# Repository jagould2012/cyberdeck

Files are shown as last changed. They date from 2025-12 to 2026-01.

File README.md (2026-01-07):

# cyberdeck
A custom build of Kali Linux Raspberry Pi’s, fun little radios, all packaged in a portable Pelican case.

### Documentation

Documentation site can be found at [https://jagould2012.github.io/cyberdeck](https://jagould2012.github.io/cyberdeck)

### Bill of Materials

A complete bill of materials can be found [here](https://github.com/jagould2012/cyberdeck/blob/main/bom.csv).

### Custom Plate

The custom plate was manufactured by DataPro using their online [designer](https://www.datapro.net/cgi-bin/plate-designer-pro). All hole and part coordinates can be found [here](https://github.com/jagould2012/cyberdeck/blob/main/plate_drill.csv).

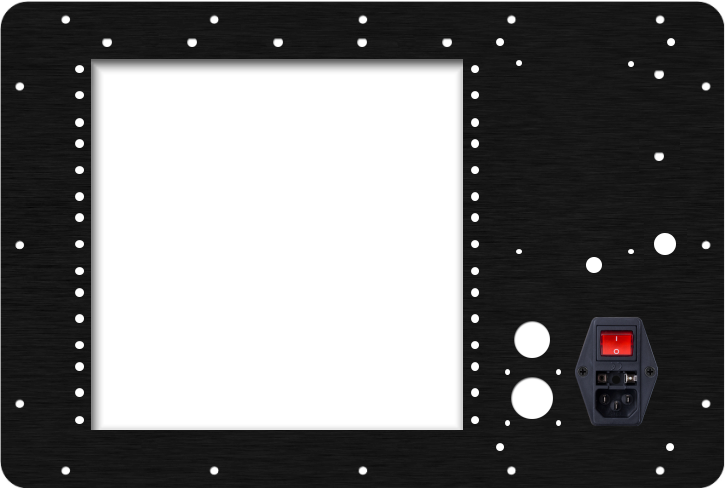
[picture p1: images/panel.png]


Dxf file is available [here](https://github.com/jagould2012/cyberdeck/blob/main/dxf/Panel.dxf).

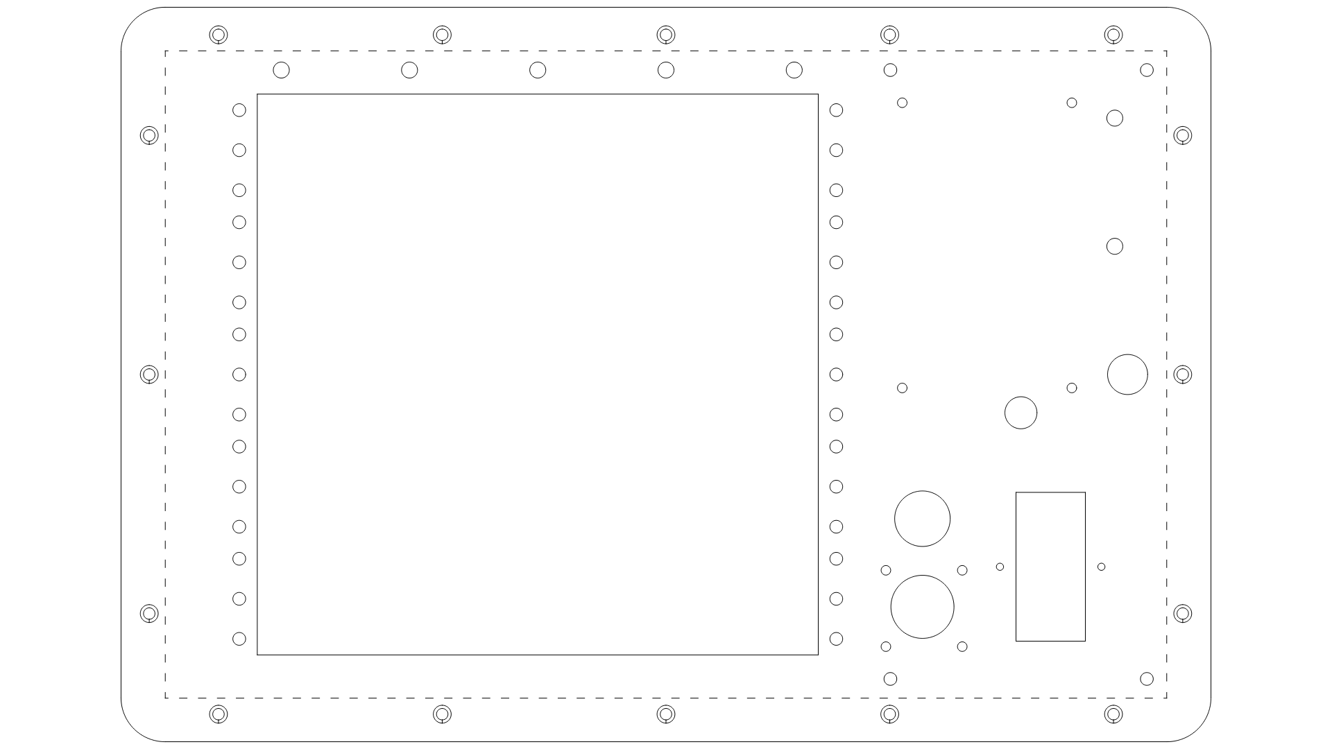
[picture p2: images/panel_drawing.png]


### Power

Wiring diagram for the power supplies, switches, and relays can be downloaded [here](https://github.com/jagould2012/cyberdeck/blob/main/images/power.png).

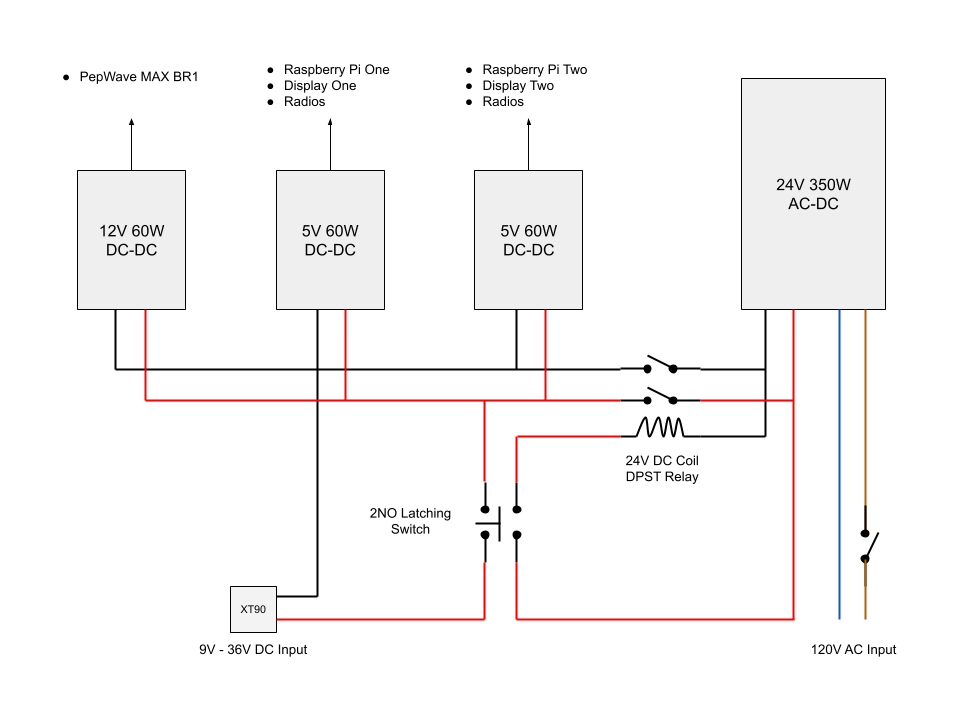
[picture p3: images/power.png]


### Internal Panels

Power supplies and USB devices are mounted to 1/8" ABS panels. Dxf files for the panels can be found [here](https://github.com/jagould2012/cyberdeck/blob/main/dxf/).

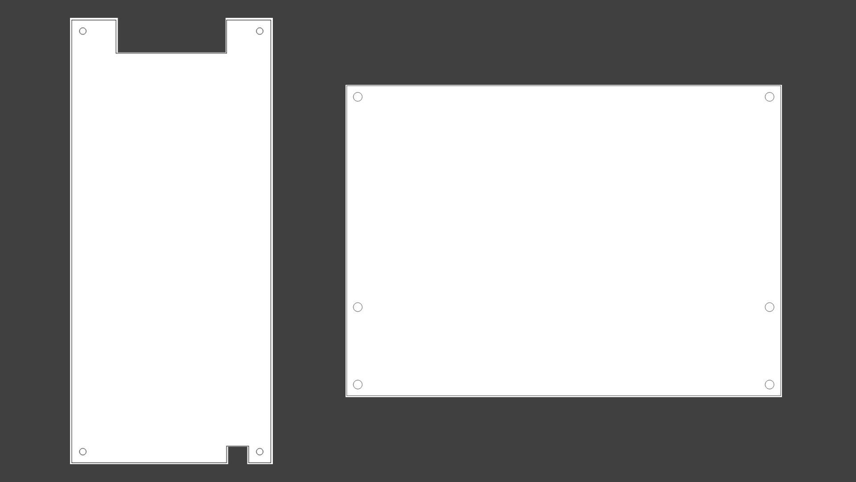
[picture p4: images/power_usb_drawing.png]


### Assembly

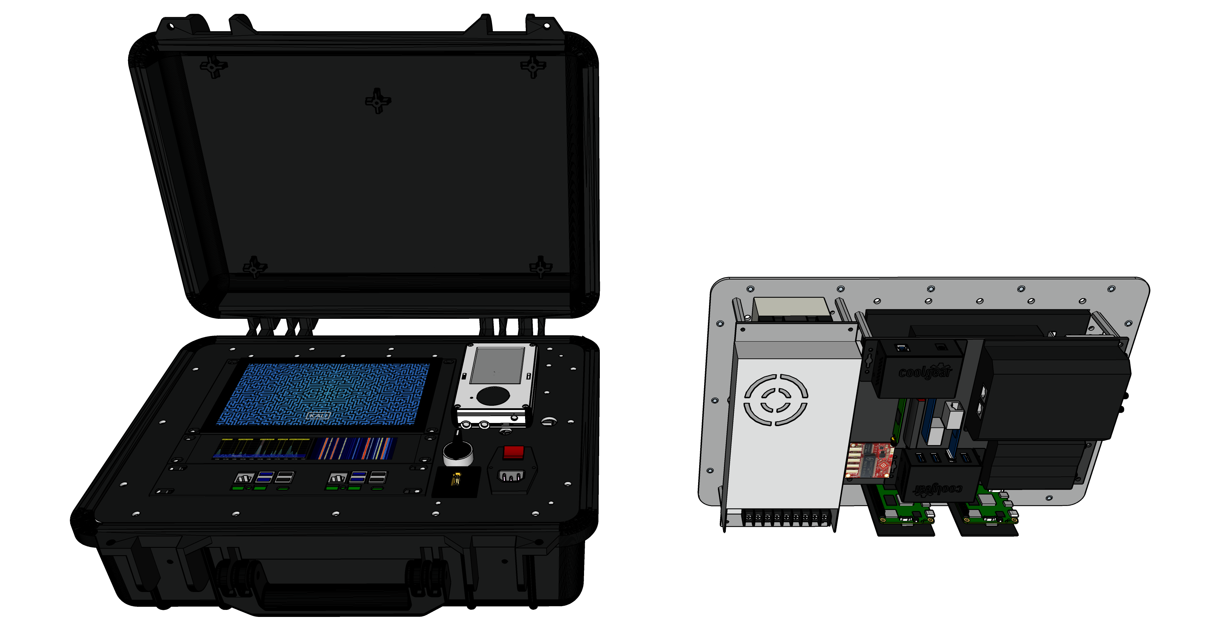
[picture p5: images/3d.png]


Sketchup model is available [here](./Cyberdeck.skp) to assist in assembly.

### Stand

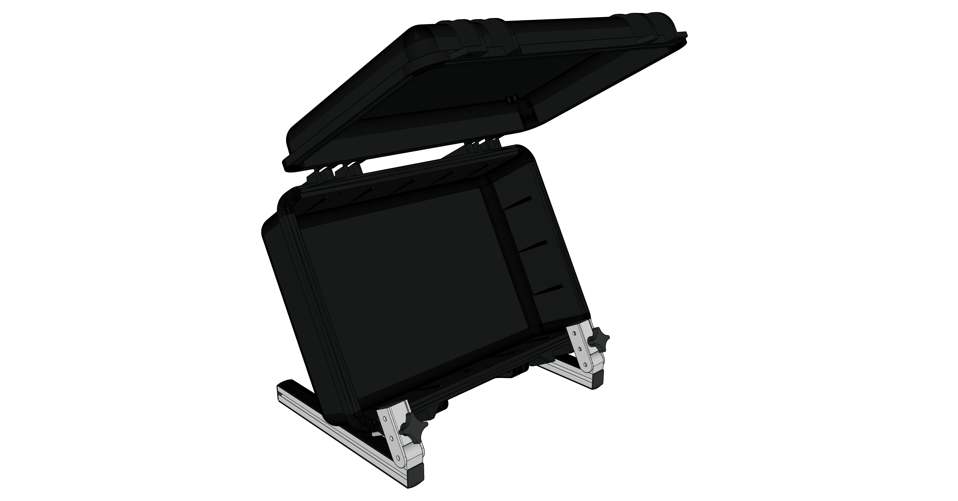
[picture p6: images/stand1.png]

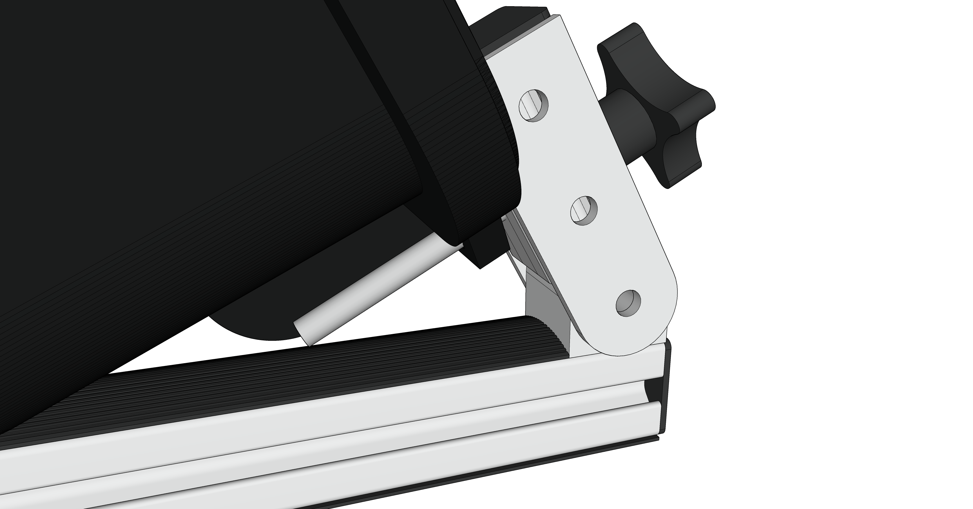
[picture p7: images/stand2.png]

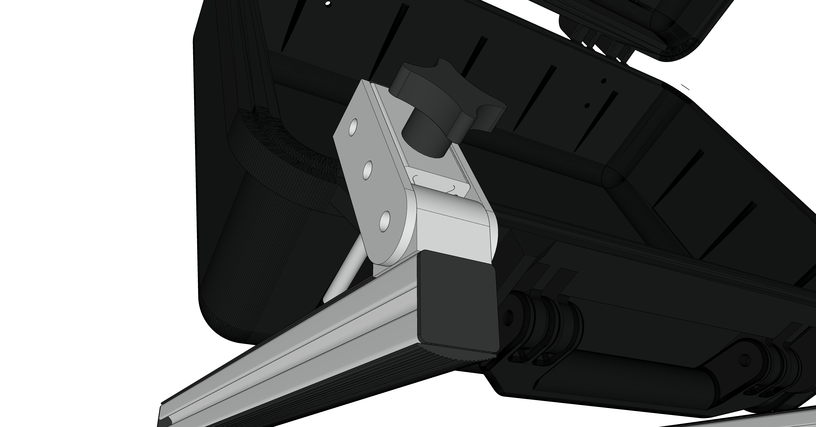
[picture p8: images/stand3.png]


An option stand design is constucted from aluminum t-slot rail.

Sketchup model of the stand is available [here](./Stand) to assist in assembly.

The stand bill of materials is available [here](stand.bom.csv).

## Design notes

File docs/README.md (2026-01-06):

# Cyberdeck
A custom build of Kali Linux Raspberry Pi’s, fun little radios, all packaged in a portable Pelican case.

### Why

Very good question. Why not? 🤷‍♂️

While many people would have varying uses for a project like this, here's a few I can personally offer:

* I had accumulated over the years a lot of interesting little boards (SDR, Ubertooth One, etc) and wanted to have them all put together in one place and be more usable.

* It was a great distraction over the 2025 holidays and gave me a much needed mental break from work.

* I'll occasionally get some professional use out of it when working on IoT projects, being able to inspect raw radio packets, etc.

* It's a lot of fun on the weekends to sit and listen to various radio traffic out there - Fire, EMS, Police, Air Traffic, etc.

* In a natural disaster, civil unrest, etc where we could possibly lose cellular and internet access - it could become quite useful to get comms up with the outside world.

* Lets face it, between the radios in the project and capabilities of Kali Linux, this is a giant rabbit hole of learning. I love to learn new things, and this will bring years of enjoyment.

### Parts

* A complete bill of materials can be found [here](https://github.com/jagould2012/cyberdeck/blob/main/bom.csv) for the project.
* The optional stand bill of materials is [here](https://github.com/jagould2012/cyberdeck/blob/main/stand.bom.csv).

### Cost

While many enthusiasts have a lot of these parts laying around from previous projects (Raspberry Pi, power supplies, assorted cables), if you were to start from scratch and order each item, the cost of the materials is about $3400. The optional stand is about $150 to build. 
<br><sub>(Prices as of Jan 6, 2026)</sub>

### Technical Materials

* All software, drawings, 3D models (Sketchup) can be found in the Github [repository](https://github.com/jagould2012/cyberdeck).

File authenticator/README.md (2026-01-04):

# Cyberdeck Login

A BLE-based remote authentication system for Raspberry Pi computers. Authenticate to your devices from your iPhone without typing passwords.

## Overview

Cyberdeck Login allows you to unlock your Raspberry Pi (or other Linux) computers remotely via Bluetooth Low Energy (BLE). The system uses public key cryptography to ensure secure, passwordless authentication.

### How It Works

1. **Server** advertises via BLE when the device is locked/away, broadcasting:
   - Computer name
   - Random nonce (changes frequently)
   - Timestamp

2. **iPhone App** detects the advertisement, signs the nonce with its private key, and sends back the signed response via BLE

3. **Server** verifies the signature against registered public keys and triggers PAM login for the configured user

### Security Features

- **Public Key Cryptography**: Ed25519 signatures for authentication
- **Nonce-based**: Fresh nonce for each authentication attempt
- **Replay Attack Prevention**: Nonces are invalidated immediately after use and rotate frequently
- **No Password Transmission**: Only cryptographic signatures are exchanged

## Project Structure

```
cyberdeck-login/
├── README.md           # This file
├── server/             # Node.js BLE server
│   ├── Dockerfile
│   ├── docker-compose.yml
│   ├── package.json
│   └── src/
├── config/             # PAM configuration and scripts
│   └── README.md
└── app/                # iOS Swift app example code
    └── README.md
```

## Quick Start

### 1. Set Up the Server

```bash
cd server
docker-compose up -d
```

### 2. Configure PAM

Follow the instructions in `config/README.md` to install the PAM module.

### 3. Register Your iPhone

1. Put the server in registration mode:
   ```bash
   docker exec cyberdeck-login-server node register-mode.js
   ```

2. In the iOS app, go to Settings → Register Device

3. The server will capture your public key in the `publicKeys/` directory

4. Manually move the key to `config.json`:
   ```bash
   # Review the captured key
   cat data/publicKeys/<device-id>.json
   
   # Add it to config.json registered devices
   ```

### 4. Test Authentication

Lock your Raspberry Pi and use the iOS app to authenticate!

## Configuration

### Server Configuration (`data/config.json`)

```json
{
  "computerName": "my-raspberry-pi",
  "loginUser": "pi",
  "nonceRotationIntervalMs": 30000,
  "registeredDevices": [
    {
      "name": "My iPhone",
      "publicKey": "base64-encoded-ed25519-public-key"
    }
  ]
}
```

### Volume Mounts

The server expects a `data/` volume containing:
- `config.json` - Main configuration
- `publicKeys/` - Directory for captured public keys during registration

## Requirements

### Server (Raspberry Pi)
- Docker and Docker Compose
- Bluetooth 4.0+ adapter
- Linux with PAM support

### iOS App
- iOS 14.0+
- iPhone with Bluetooth

## Security Considerations

1. **Physical Security**: The server must be physically secured as it can bypass password authentication

2. **Key Management**: Protect your private keys on both server and mobile device

3. **Registration Mode**: Only enable registration mode when actively pairing a new device

4. **Network**: BLE has limited range (~10m), providing implicit proximity verification

## License

MIT License - See LICENSE file for details

## Contributing

Contributions welcome! Please read CONTRIBUTING.md before submitting PRs.

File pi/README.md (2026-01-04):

# Cyberdeck Raspberry Pi Setup

Automated setup for Raspberry Pi devices running Kali Linux with SDR software stack, Docker, and Synchronet BBS.

## Quick Start

### 1. Flash Kali Linux

1. Download a Kali Linux ARM64 image
2. Flash to SD card with Raspberry Pi Imager
3. Boot the Raspberry Pi
4. (Optional) Install to NVMe:
   ```bash
   wget http://archive.raspberrypi.org/debian/pool/main/r/rpi-imager/rpi-imager_2.0.1_arm64.deb
   sudo dpkg -i rpi-imager_2.0.1_arm64.deb
   sudo rpi-imager &
   ```
5. Use rpi-imager to install Kali Linux to the NVMe drive
6. Remove the SD card and reboot

Recommended at this point to install available updates:

```
sudo apt-get update && sudo apt upgrade -y && sudo apt dist-upgrade -y && sudo reboot
```

### 2. Initial Network Setup

Before running Ansible, ensure the Pi is accessible:

```bash
# Install your SSH key (from Mac/controller)
ssh-copy-id kali@<pi-ip-address>
```

### 3. Run Ansible Playbooks

From the `ansible/` directory on your controller machine:

```bash
# Install dependencies
ansible-galaxy collection install -r requirements.yml

# Run full setup on all hosts
ansible-playbook site.yml -K

# Or target specific hosts (include localhost for BBS deployment)
ansible-playbook site.yml -K --limit "localhost,cyberdeck-pi1"

# Or run individual playbooks
ansible-playbook playbooks/docker-install.yml -K --limit cyberdeck-pi1
```

## What Gets Installed

The Ansible playbooks configure:

- **System Configuration**
  - Boot config (HDMI hotplug, fan control, USB power)
  - Custom hostname
  - WiFi MAC override (for duplicate MAC issues)
  - SSH host key regeneration
  - Sleep/suspend disabled

- **Networking**
  - NetworkManager as primary network manager
  - mDNS/Avahi for `.local` hostname resolution
  - Conflicting services disabled (netplan, systemd-networkd)

- **Docker**
  - Docker CE with compose plugin
  - QEMU user-mode emulation for cross-architecture containers
  - Portainer web UI

- **SDR Software**
  - SDR++ (sdrpp)
  - Universal Radio Hacker (urh)
  - SDRAngel (sdrangel)
  - Base SDR dependencies and udev rules

- **Synchronet BBS**
  - Pre-built Docker container
  - ARM64 native build with SpiderMonkey fix

## Directory Structure

```
pi/
├── ansible/           # Ansible playbooks and configuration
│   ├── inventory.yml  # Host definitions
│   ├── site.yml       # Main orchestration playbook
│   └── playbooks/     # Individual playbooks
├── bbs/               # Synchronet BBS Docker setup
├── sdrangel/          # SDRAngel Docker builder
└── kernel/            # Custom kernel build (optional)
```

## Inventory

Edit `ansible/inventory.yml` to configure your hosts:

```yaml
raspberry_pis:
  children:
    pi:
      hosts:
        cyberdeck-pi1:
          ansible_host: 10.0.0.100
          custom_hostname: cyberdeck-pi1
        cyberdeck-pi2:
          ansible_host: 10.0.0.101
          custom_hostname: cyberdeck-pi2
          wifi_mac_override: "AA:BB:CC:DD:EE:FF"  # Optional
```

## Custom Kernel (Optional)

The default Kali kernel for Raspberry Pi uses 16KB page sizes. Some software requires 4KB pages (e.g., certain Node.js modules like Sharp).

Check your current page size:
```bash
getconf PAGESIZE
```

If you need 4KB pages, see the `kernel/` directory for a Dockerfile that builds a custom kernel. Note: This affects system performance and should only be used when necessary.

## Troubleshooting

### Network Issues

If mDNS isn't working:

```bash
# Check avahi is running
sudo systemctl status avahi-daemon

# Check NetworkManager is managing interfaces
nmcli device status
```

## Manual Commands Reference

While Ansible handles everything, here are useful manual commands:

```bash
# Reboot a host
ansible-playbook playbooks/reboot.yml -K --limit cyberdeck-pi1

# Check BBS status
ssh cyberdeck-pi1.local "docker logs -f SynchronetBBS"

# Connect to BBS
ssh -p 10022 cyberdeck-pi1.local
```

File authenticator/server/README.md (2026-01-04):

# Cyberdeck Login Server

Node.js BLE server that handles authentication requests from the iOS app.

## Prerequisites

- Docker and Docker Compose (for production)
- Node.js 18+ (for development)
- Bluetooth 4.0+ adapter (or use proxy mode for VMs)
- Linux system with D-Bus (for lock screen monitoring)

## Quick Start

1. **Configure environment**

   ```bash
   cp .env.example .env
   nano .env
   ```

2. **Install dependencies**

   ```bash
   npm install
   ```

3. **Start the server**

   ```bash
   npm run dev
   ```

## Configuration

### Environment Variables (`.env`)

```bash
# Path to config.json
CONFIG_PATH=./data/config.json

# Directory for captured public keys during registration
PUBLIC_KEYS_DIR=./data/publicKeys

# Computer name shown in BLE advertisement
COMPUTER_NAME=cyberdeck

# Linux user to log in
LOGIN_USER=pi

# BLE Mode: 'native' for real Bluetooth, 'tcp' for proxy mode
BLE_MODE=native

# TCP port for proxy mode (only used when BLE_MODE=tcp)
TCP_PORT=3100
```

### Server Settings (`data/config.json`)

```json
{
  "computerName": "my-raspberry-pi",
  "loginUser": "pi",
  "nonceRotationIntervalMs": 30000
}
```

## Directory Structure

```
data/
├── config.json      # Server settings
├── publicKeys/      # Captured keys from registration attempts
│   └── <device-id>.json
└── registered/      # Approved devices (copy files here to enable)
    └── <device-id>.json
```

## Device Registration

Registration is always enabled. When an iPhone registers, its public key is saved to `publicKeys/`. To approve a device, copy its file to `registered/`.

1. **Register from iPhone app** (Settings → Register Device)
   
   Server logs:
   ```
   📝 Registration request from: Jonathan's iPhone
   📝 Captured public key saved to ./data/publicKeys/ABC123.json
      To register: cp ./data/publicKeys/ABC123.json ./data/registered/
   ```

2. **Review the captured key**

   ```bash
   cat data/publicKeys/ABC123.json
   ```

3. **Approve the device**

   ```bash
   cp data/publicKeys/ABC123.json data/registered/
   ```

   Server auto-detects and logs:
   ```
   🔑 1 registered device(s) in ./data/registered
      ✨ New device(s) added!
   ```

4. **Revoke a device**

   ```bash
   rm data/registered/ABC123.json
   ```

   Server logs:
   ```
   🔑 0 registered device(s) in ./data/registered
      🗑️  Device(s) removed
   ```

## Proxy Mode (for VMs)

If running in a VM without Bluetooth access, use proxy mode. A Mac with Bluetooth acts as a BLE bridge.

### Architecture

```
iPhone ←→ BLE ←→ Mac (proxy) ←→ WebSocket ←→ VM (server)
```

### Setup

**On the VM:**

```bash
# Set proxy mode in .env
echo "BLE_MODE=tcp" >> .env
echo "TCP_PORT=3100" >> .env

# Start server
npm run dev
```

Output:
```
📡 BLE Mode: tcp
📡 WebSocket server listening on port 3100
✅ Cyberdeck Login Server running (proxy mode)
   Waiting for proxy connection on port 3100...
```

**On the Mac:**

```bash
cd tools/ble-proxy
npm install
npm start -- --server <VM_IP>:3100
```

Output:
```
🔗 BLE Proxy - connecting to ws://<VM_IP>:3100
✅ Connected to server
🔗 Server ready
📡 Bluetooth: poweredOn
✅ BLE advertising - iPhone can now connect
```

Now the iPhone app will see "CyberdeckProxy" and can authenticate through the VM.

## BLE Service Details

### Service UUID: `CD10`

### Characteristics

| UUID | Name | Properties | Description |
|---|---|---|---|
| `CD11` | Challenge | Read | Returns current challenge (nonce, timestamp, computerName) |
| `CD12` | Auth | Write | Accepts signed authentication response |
| `CD13` | Register | Write | Accepts public key registration |

### Challenge Format (JSON)

```json
{
  "nonce": "base64-encoded-32-byte-random",
  "timestamp": 1699999999999,
  "computerName": "my-raspberry-pi"
}
```

### Auth Request Format (JSON)

```json
{
  "signedNonce": "base64-encoded-ed25519-signature",
  "publicKey": "base64-encoded-public-key"
}
```

## Docker Deployment

```bash
docker-compose up -d
```

The container needs:
- Privileged mode (for Bluetooth)
- Host network (for BLE)
- Volume mounts for `/data` and D-Bus

## Troubleshooting

### Bluetooth not working

```bash
# Check Bluetooth status
bluetoothctl show

# Restart Bluetooth service
sudo systemctl restart bluetooth

# Verify adapter is visible
hciconfig
```

### D-Bus errors

```bash
export DBUS_SESSION_BUS_ADDRESS="unix:path=/run/user/$(id -u)/bus"
npm run dev
```

### Lock screen not detected

The server supports:
- systemd-logind (via `loginctl`)
- GNOME Screensaver (via D-Bus)
- KDE Screensaver (via D-Bus)
- freedesktop.org Screensaver standard

### Proxy mode connection issues

```bash
# Check VM is reachable
ping <VM_IP>

# Check port is open
nc -zv <VM_IP> 3100

# Check server is listening
# On VM:
ss -tlnp | grep 3100
```

## Architecture

```
┌─────────────────────────────────────────────────────┐
│                   CyberdeckLoginServer              │
├─────────────────────────────────────────────────────┤
│                                                     │
│  Native Mode:           Proxy Mode:                 │
│  ┌─────────────┐        ┌─────────────┐            │
│  │BleAdvertiser│        │ WsBleServer │            │
│  │BlePeripheral│        │ (WebSocket) │            │
│  └──────┬──────┘        └──────┬──────┘            │
│         │                      │                    │
│  ┌──────┴──────────────────────┴──────┐            │
│  │            AuthService             │            │
│  │       (Ed25519 verification)       │            │
│  └──────────────────┬─────────────────┘            │
│                     │                               │
│  ┌──────────────────┴─────────────────┐            │
│  │           ConfigManager            │            │
│  │    (watches registered/ folder)    │            │
│  └──────────────────┬─────────────────┘            │
│                     │                               │
│  ┌──────────────────┴─────────────────┐            │
│  │             PamAuth                │            │
│  │      (trigger system login)        │            │
│  └────────────────────────────────────┘            │
└─────────────────────────────────────────────────────┘
```

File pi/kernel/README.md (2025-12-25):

# Kali Linux Kernel Builder for Raspberry Pi 5 (4KB Pages)

This Dockerfile creates a build environment for compiling the Kali Linux kernel with
the Raspberry Pi 5 configuration, modified to use **4KB page size** instead of the
default 16KB page size.

## Why 4KB Page Size?

The Raspberry Pi 5 (BCM2712) kernel defaults to 16KB pages for improved performance
in certain workloads. However, some software and use cases require or benefit from
4KB pages:

- Better memory efficiency for applications with small allocations
- Compatibility with software that assumes 4KB pages
- Reduced memory fragmentation in some scenarios
- Required for certain virtualization and container workloads

## Prerequisites

- Docker installed on your Mac M4 (or other ARM64 system)
- At least 20GB of free disk space
- Internet connection for downloading kernel source

## Quick Start

### 1. Build the Docker image

```bash
docker build -t kali-rpi5-kernel .
```

This will:
- Pull the latest Kali Linux rolling release
- Install all kernel build dependencies
- Clone the Raspberry Pi Linux kernel source (rpi-6.6.y branch)
- Apply the bcm2712_defconfig (Raspberry Pi 5)
- Modify the config to use 4KB pages

### 2. Build the kernel

```bash
mkdir -p output
docker run -it --rm -v $(pwd)/output:/output kali-rpi5-kernel /build/build-kernel.sh
```

This will compile the kernel and copy the artifacts to `./output/`:
- `boot/kernel8-4k.img` - The kernel image
- `boot/*.dtb` - Device tree blobs
- `boot/overlays/` - Device tree overlays
- `modules/lib/modules/<version>/` - Kernel modules
- `kernel-config-4k` - The kernel configuration used

### 3. Install on Raspberry Pi 5

1. Copy the kernel and DTBs:
   ```bash
   sudo cp output/boot/kernel8-4k.img /boot/firmware/
   sudo cp output/boot/*.dtb /boot/firmware/
   sudo cp -r output/boot/overlays/* /boot/firmware/overlays/
   ```

2. Install the modules:
   ```bash
   sudo cp -r output/modules/lib/modules/* /lib/modules/
   sudo depmod -a
   ```

3. Configure boot to use the new kernel:
   ```bash
   echo "kernel=kernel8-4k.img" | sudo tee -a /boot/firmware/config.txt
   ```

4. Reboot:
   ```bash
   sudo reboot
   ```

5. Verify after reboot:
   ```bash
   uname -r  # Should show the new kernel version with -v8-4k-kali suffix
   getconf PAGESIZE  # Should return 4096 (4KB)
   ```

## Additional Commands

### View current configuration
```bash
docker run -it --rm kali-rpi5-kernel /build/show-config.sh
```

### Interactive shell
```bash
docker run -it --rm kali-rpi5-kernel bash
```

### Run menuconfig for additional customization
```bash
docker run -it --rm -v $(pwd)/output:/output kali-rpi5-kernel \
    bash -c "cd /build/linux && make menuconfig && /build/build-kernel.sh"
```

### Use a different kernel branch
```bash
docker build --build-arg KERNEL_BRANCH=rpi-6.12.y -t kali-rpi5-kernel .
```

## Configuration Changes

The only modification made to the stock `bcm2712_defconfig` is:

| Setting | Original | Modified |
|---|---|---|
| `CONFIG_ARM64_16K_PAGES` | `y` | not set |
| `CONFIG_ARM64_4K_PAGES` | not set | `y` |
| `CONFIG_LOCALVERSION` | `"-v8-16k"` | `"-v8-4k-kali"` |

## Build Time

On a Mac M4:
- Docker image build: ~5-10 minutes
- Kernel compilation: ~15-30 minutes (depending on CPU cores)

## Troubleshooting

### Build fails with out of memory
Increase Docker's memory allocation in Docker Desktop settings.

### Modules don't load after installation
Run `sudo depmod -a` and ensure the module directory name matches `uname -r`.

### Kernel panic on boot
The 4KB page size kernel may not be compatible with all Raspberry Pi 5 
configurations. You can revert by removing `kernel=kernel8-4k.img` from 
`/boot/firmware/config.txt` (edit the SD card on another computer if needed).

## References

- [Raspberry Pi Linux Kernel](https://github.com/raspberrypi/linux)
- [Kali ARM Build Scripts](https://gitlab.com/kalilinux/build-scripts/kali-arm)
- [Raspberry Pi Kernel Documentation](https://www.raspberrypi.com/documentation/computers/linux_kernel.html)

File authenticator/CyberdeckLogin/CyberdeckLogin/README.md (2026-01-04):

# Cyberdeck Login iOS App

Example Swift code for the Cyberdeck Login iOS app.

## Overview

This directory contains example Swift code demonstrating the core functionality needed for the iOS app. You will need to create an Xcode project and integrate this code.

## Project Setup

1. Create a new iOS project in Xcode
   - Product Name: `Cyberdeck Login`
   - Bundle Identifier: `com.yourcompany.cyberdeck-login`
   - Language: Swift
   - Minimum iOS: 14.0

2. Add required capabilities in Xcode:
   - Background Modes → Uses Bluetooth LE accessories
   - Background Modes → Acts as a Bluetooth LE accessory (for registration)

3. Add to Info.plist:
   ```xml
   <key>NSBluetoothAlwaysUsageDescription</key>
   <string>Cyberdeck Login uses Bluetooth to authenticate with your devices</string>
   <key>NSBluetoothPeripheralUsageDescription</key>
   <string>Cyberdeck Login uses Bluetooth to authenticate with your devices</string>
   ```

4. Copy the Swift files from this directory into your project

## File Structure

```
app/
├── README.md                 # This file
├── CyberdeckLoginApp.swift   # Main app entry point
├── Models/
│   ├── Device.swift          # Device model
│   └── KeyPair.swift         # Cryptographic key pair
├── Services/
│   ├── BLEManager.swift      # Bluetooth LE manager
│   ├── CryptoService.swift   # Ed25519 signing
│   └── KeychainService.swift # Secure key storage
├── Views/
│   ├── ContentView.swift     # Main view
│   ├── DeviceListView.swift  # Nearby devices list
│   ├── DeviceDetailView.swift# Single device view
│   └── SettingsView.swift    # Settings & registration
└── ViewModels/
    └── DeviceViewModel.swift # Device state management
```

## Core Components

### BLE Service UUIDs

```swift
let CYBERDECK_SERVICE_UUID = CBUUID(string: "CD10")
let CHALLENGE_CHAR_UUID = CBUUID(string: "CD11")
let AUTH_CHAR_UUID = CBUUID(string: "CD12")
let REGISTER_CHAR_UUID = CBUUID(string: "CD13")
```

### Authentication Flow

1. **Discover** nearby Cyberdeck devices (scanning for `CD10` service)
2. **Connect** to the device
3. **Read** the challenge from `CD11` characteristic (nonce + timestamp)
4. **Sign** the challenge with device's Ed25519 private key
5. **Write** signed response to `CD12` characteristic
6. **Receive** success/failure result

### Key Management

- Keys are generated using Ed25519 (via CryptoKit on iOS 13+ or TweetNaCl)
- Private key stored securely in iOS Keychain
- Public key can be exported for registration

## Dependencies

The example code uses only Apple frameworks:
- `CoreBluetooth` - BLE communication
- `CryptoKit` - Ed25519 signing (iOS 13+)
- `Security` - Keychain access

## Building

1. Open your Xcode project
2. Copy the Swift files into your project
3. Build and run on a physical device (BLE doesn't work in simulator)

## Usage

### First Time Setup

1. Open the app
2. Go to Settings → Generate Keys (if not already done)
3. Put your Raspberry Pi server in registration mode
4. Tap "Register Device" in the app
5. Wait for registration confirmation

### Authentication

1. Lock your Raspberry Pi
2. Open the app on your iPhone
3. The device should appear in the list
4. Tap to authenticate
5. Your Raspberry Pi should unlock!

## Troubleshooting

### Device not appearing
- Ensure Bluetooth is enabled on both devices
- Check that the server is running and in locked state
- Verify BLE advertising is working

### Authentication failing
- Check that your public key is registered in config.json
- Verify system clocks are synchronized (within 60 seconds)
- Check server logs for detailed error messages

### Keys not generating
- Ensure the app has Keychain access
- Try deleting and regenerating keys in Settings

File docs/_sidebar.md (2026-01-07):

<!-- GENERATED FILE - DO NOT EDIT -->
* [Home](/)
* Instructions
  * [Pelican Case](/instructions/case.md)
  * [Power Board](/instructions/power.md)
  * [USB Board](/instructions/usb.md)
  * [Front Plate](/instructions/front.md)
  * [Assembly and Power Up](/instructions/assembly.md)
  * [Software](/instructions/software.md)
* [Gallery](/gallery.md)

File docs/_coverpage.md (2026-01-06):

<!-- _coverpage.md -->



# Cyberdeck <small>1.0</small>

> A case full of interesting tools.

[GitHub](https://github.com/jagould2012/cyberdeck)
[Get Started](#cyberdeck)

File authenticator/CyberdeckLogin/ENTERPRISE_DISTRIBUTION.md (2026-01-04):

# Enterprise Distribution Guide

This guide covers distributing the Cyberdeck Login app without using the App Store.

## Distribution Options

### Option 1: Apple Developer Enterprise Program (Recommended for organizations)
- Requires Apple Developer Enterprise Program membership ($299/year)
- Can distribute to unlimited devices within your organization
- No App Store review required

### Option 2: Ad Hoc Distribution (Up to 100 devices)
- Requires standard Apple Developer Program ($99/year)
- Limited to 100 registered devices per year
- Good for small teams or personal use

### Option 3: TestFlight (Up to 10,000 testers)
- Requires standard Apple Developer Program
- App review required (but lighter than App Store)
- Good for beta testing

## Ad Hoc Distribution Setup

### 1. Register Devices

Collect UDIDs from all target devices:

```bash
# On Mac with device connected:
system_profiler SPUSBDataType | grep -A 11 "iPhone\|iPad"

# Or use Apple Configurator 2
# Or: Settings → General → About → tap Serial Number until UDID appears
```

Register devices in Apple Developer Portal:
1. Go to https://developer.apple.com/account/resources/devices/list
2. Click (+) to add device
3. Enter device name and UDID

### 2. Create Distribution Certificate

1. On your Mac, open Keychain Access
2. Keychain Access → Certificate Assistant → Request a Certificate from a Certificate Authority
3. Enter email, select "Saved to disk"
4. Go to Apple Developer Portal → Certificates
5. Create new certificate: **Apple Distribution**
6. Upload the CSR file
7. Download and double-click to install

### 3. Create Provisioning Profile

1. Go to Apple Developer Portal → Profiles
2. Click (+) to create new profile
3. Select **Ad Hoc** distribution
4. Select your App ID (or create one: `com.yourcompany.CyberdeckLogin`)
5. Select your Distribution Certificate
6. Select all devices that should be able to install
7. Name it: `CyberdeckLogin AdHoc`
8. Download the `.mobileprovision` file

### 4. Configure Xcode Project

1. Open project in Xcode
2. Select the project → Signing & Capabilities
3. Uncheck "Automatically manage signing"
4. For **Release** configuration:
   - Import the provisioning profile (drag to Xcode or double-click)
   - Select the profile in "Provisioning Profile" dropdown
   - Select the distribution certificate

### 5. Archive and Export

1. Select **Any iOS Device** as build target
2. Product → Archive
3. When archive completes, click **Distribute App**
4. Select **Release Testing** (adhoc)
5. Choose options:
   - App Thinning: None (or All compatible device variants)
   - Include manifest for over-the-air installation: ✓ (optional)
6. Select your distribution certificate
7. Click **Export**

### 6. Distribution Methods

#### A. Direct Installation via Xcode
1. Connect device to Mac
2. Window → Devices and Simulators
3. Drag .ipa file onto device

#### B. Apple Configurator 2
1. Open Apple Configurator 2
2. Connect device
3. Add → Apps → Choose the .ipa file

#### C. Over-the-Air (OTA) Installation
Requires a web server with HTTPS.

1. During export, check "Include manifest for over-the-air installation"
2. Enter the URLs where files will be hosted:
   - IPA URL: `https://yourserver.com/apps/CyberdeckLogin.ipa`
   - Display Image URL: `https://yourserver.com/apps/icon-57.png`
   - Full Size Image URL: `https://yourserver.com/apps/icon-512.png`

3. Upload to your server:
   - `CyberdeckLogin.ipa`
   - `manifest.plist`
   - Icon images

4. Create an HTML page with install link:
```html
<!DOCTYPE html>
<html>
<head>
    <title>Install Cyberdeck Login</title>
    <meta name="viewport" content="width=device-width, initial-scale=1">
</head>
<body>
    <h1>Cyberdeck Login</h1>
    <a href="itms-services://?action=download-manifest&url=https://yourserver.com/apps/manifest.plist">
        Install App
    </a>
</body>
</html>
```

5. Users visit the page on their iOS device and tap to install

**Note:** The server must use HTTPS with a valid certificate.

#### D. MDM (Mobile Device Management)
For larger organizations, use an MDM solution like:
- Jamf
- Microsoft Intune
- Kandji
- Mosyle

## Watch App Distribution

The Watch app is bundled with the iPhone app automatically:

1. Ensure Watch target is included in the archive
2. The .ipa will contain both iPhone and Watch apps
3. When user installs iPhone app, Watch app is available in Watch app on iPhone

## Updating the App

For Ad Hoc distribution, you need to:
1. Increment the version/build number in Xcode
2. Create a new archive
3. Export with the same provisioning profile
4. Distribute the new .ipa

Users will need to install the new version manually (OTA link or direct install).

## Troubleshooting

### "Unable to Install" Error
- Device UDID not in provisioning profile
- Provisioning profile expired
- App was built for different architecture

### Profile Expired
- Provisioning profiles expire after 1 year
- Create new profile and re-export

### Device Limit Reached
- Ad Hoc is limited to 100 devices per year
- Devices cannot be removed until membership renewal
- Consider Enterprise program for more devices

## Automation with fastlane

For automated builds, use fastlane:

```ruby
# Fastfile
default_platform(:ios)

platform :ios do
  desc "Build and export Ad Hoc IPA"
  lane :adhoc do
    # Increment build number
    increment_build_number
    
    # Build
    build_app(
      scheme: "CyberdeckLogin",
      export_method: "ad-hoc",
      output_directory: "./build",
      output_name: "CyberdeckLogin.ipa"
    )
    
    # Optional: Upload to distribution server
    # scp("./build/CyberdeckLogin.ipa", "user@server:/var/www/apps/")
  end
end
```

Run with:
```bash
fastlane adhoc
```

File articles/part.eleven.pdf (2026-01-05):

## Part Eleven: The Software

medium.com/@jagould2012/part-eleven-the-software-eb3590c60b6b

(side note, Eleven is dead. I don’t believe.)

Automated Configuration

With the build complete (mostly) (https://medium.com/@jagould2012/cyberdeck-part-ten-2958a534caa5) I moved on to the software design of the system. A few key requirements:

All software should be installed on both computers (redundant compute design). While a board is configured to run a certain set of software on boot, it should be able to take over the role of the other board (run Pi 2 boot script on Pi 1 for example)
It should be easy to keep the software installs in sync across boards.
Software should be easy to test on my laptop without necessarily having the case powered up in front of me.

For this task, I turned to my friend (or arch enemy?) Ansible. (https://docs.ansible.com/) Consisting of Playbooks (https://docs.ansible.com/projects/ansible/latest/playbook_guide/playbooks_intro.html#playbook-syntax) (install scripts) and a host Inventory (https://docs.ansible.com/projects/ansible/latest/inventory_guide/intro_inventory.html) (list of target computers), Ansible is an automation software that remotely configures computers over SSH. It’s primarily used for managing large fleets of servers, but can easily be used to maintain desktop computers also. The big advantage is that the configuration can be checked into a source repository, versioned, and updated just like a software project (referred to as “infrastructure as code”).

Let’s face it, if you’ve used Ansible, its a great tool — once you have it working correctly — but you always do question was the time it took to get it working worth what it buys you? However, times have changed, and my other friend / nemesis Claude knows Ansible quite well, so the upfront investment is a lot less than it used to be.

The Ansible configuration, available here, (https://github.com/jagould2012/cyberdeck/tree/main/pi/ansible) does a couple of things:

Builds a few projects on my local machine (conveniently an ARM64 mac) to save time not building on each remote host. This includes the BBS software (Synchronet) and SDRAngel, both of which do not have pre-build ARM packages available for the Pi. Copies and installs all software to each Raspberry Pi and applies global settings I want on every host (disable sleep, configure Network Manager, etc).
Applies host specific configurations — MAC address configuration, which Docker containers should start, etc.
Configures a 3rd host, cyberdeck-testvm.local, which is a copy of Kali Linux running on my Macbook in a Parallels VM.

The test VM allows me to test new software, and develop the Ansible scripts to deploy it, without having to have the Cyberdeck powered up — and more importantly not mess up the Cyberdecks configuration. Each time I sit down to add more to the stack, I can snapshot the VM and reset it if I’m not satisfied with how things turn out. Once I’m happy with my changes, I do a pull request on Github, then run the Ansible playbooks on the Raspberry Pi boards.

At any time, with a swap of the USB cable on the front panel and running a script, Pi 1 can become Pi 2, Pi 2 can become Pi 1, giving me a true redundant system. You wouldn’t want to grab the Pelican case in an emergency, natural disaster, only to find your comms down because of a $100 Raspberry Pi or $50 power supply?

Authentication

This is where the rabbit hole got very deep…

I was thinking through the other day the issue of how I will log into these computers:

I don’t want to make them insecure and have them log in automatically on boot. With just touch screens available on the system, I really hate the idea of an onscreen keyboard to type in a password.
Making the Cyberdeck useless without pulling out the keyboard breaks the whole design (even though I do have a nice keyboard conveniently in the case).

I looked into several hardware key solutions from Yubico and Thetis that use the Fido2 protocol to securely unlock a device. These were interesting options, especially the very small Thetis Nano: (https://www.amazon.com/dp/B0F3JX7F76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)

You plug in the device to a USB port, and press a button on it to initiate the authentication. Using the right PAM module on Linux, the device unlocks.
Some offer a built-in Bluetooth option that allow you to activate the key without plugging it into USB and send the authentication code. However, this is known to be unreliable at the login screen on Linux (apparently works very well in a browser for using the key to log into websites though).
I could leave the key in the USB port the majority of the time, and just remove it when I want to secure the case, but this means anyone can press the button on the key and access the computer.
The Fido2 specification requires the activation to ultimately be on the hardware key, so no options exist to use a phone app, etc to prevent the key from being used if left plugged in.

Not exactly what I was looking for. The ideal scenario to me is that I could power up the case and then use some other device, like my phone or watch, to securely login the Pi computers.

Fine. I’ll do it myself.
— Thanos

After researching the available options, I had developed a list of requirements, but found no existing solution:

Server software running on the Pi that was capable of logging in a pre-selected user. Wireless interface, no plugging in USB devices
Fast means of authenticating from a secure device I already carry daily
Secure login, not vulnerable to capture or replay attacks (I’m not the only person with a Mayhem board).

The server…

Node.js server running in a Docker container.
Advertises every few seconds on BLE and listens for a response.
Generates a new nonce every 30 seconds and updates it advertisement. Stores a list of public keys that have been received from my client app.
If I move a public key from the publicKeys directory to the registered directory, accepts authentication from that device.
When a packet is received, verifies with the public key that the nonce was signed with the matching private key and unlocks the computer.
Uses Linux dbus interface to communicate with the operating system.
Immediately rotates the nonce so that the packet, if captured by a bad actor, can never be used again.

Combined with the correct custom PAM module, we now had a secure way to remotely unlock Linux.

The app…

iPhone, iPad, and Apple Watch app capable of communicating with the server. Built with Swift.
Generates a new public / private key on install (from the settings menu).
When put in ‘register’ mode, sends the public key to the server over Bluetooth. Scans for nearby servers listening on BLE, allows you to connect, authenticate, and send the unlock command.
Using Apples secure connection between the watch and phone and iCloud Keychain, share the private key with attached watches. The watch can now directly connect to the server and send its own unlock commands.
Watch “complication” can be installed on any watch face for quickly launching the login app.

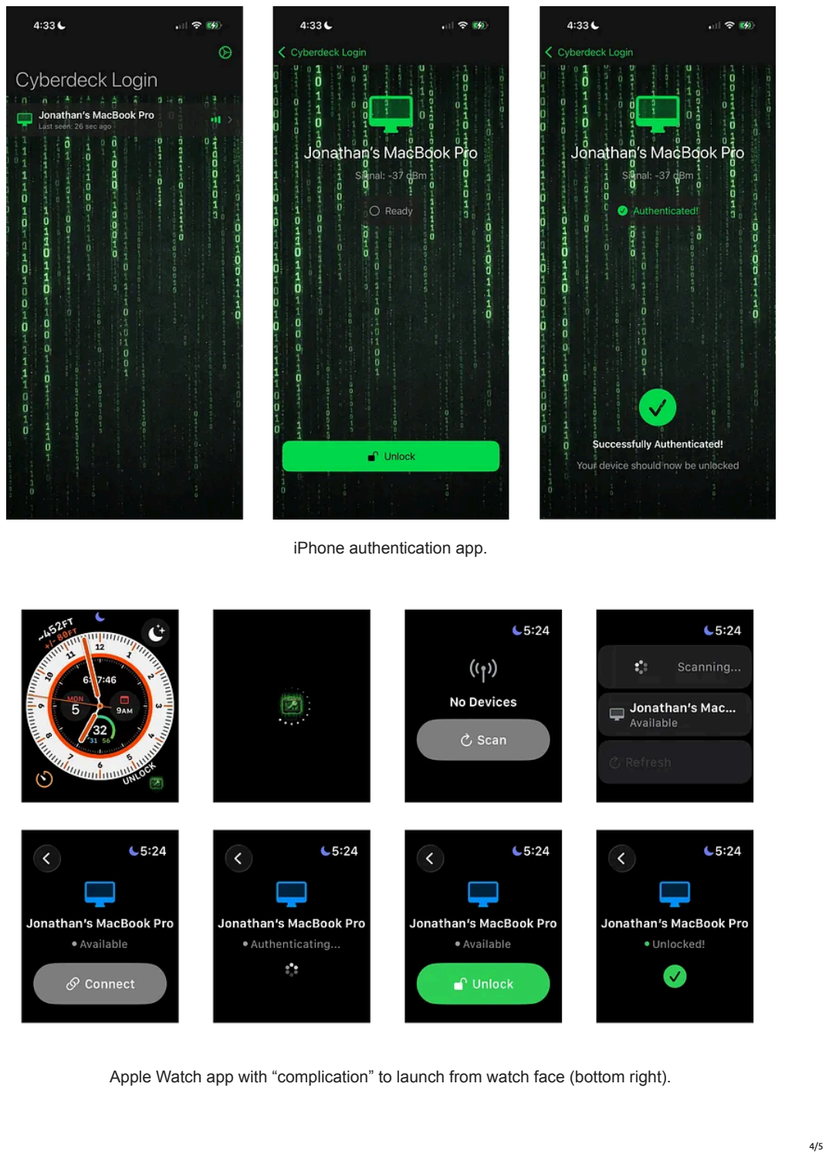
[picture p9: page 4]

iPhone authentication app.

Apple Watch app with “complication” to launch from watch face (bottom right).

Right now I’m distributing it to my personal devices under an enterprise build, but eventually would be willing to put it on the App Store if others are interested. It could become especially interesting as a Cyberdeck companion app with additional features (reboot, power off, WiFi management).

And to be clear — I am completely aware of how overbuilt a solution this is, but it was really fun to get working. And it’s all available on the Github project (https://github.com/jagould2012/cyberdeck/tree/main/authenticator) of course.

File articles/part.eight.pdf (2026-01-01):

## Cyberdeck: Part Eight

medium.com/@jagould2012/cyberdeck-part-eight-22de883a2eab

Back in the 90’s I ran a couple of different bulletin board systems (BBS). I won’t get into all the details of the various “groups” of that time, but one of my favorite BBS software I ever ran was Oblivion/2 (long live Lord Jazz / ACiD / iCE 😉)

Obv/2 is long gone, and despite attempts (https://github.com/M-griffin/Oblivion2-XRM) to resurrect it, no production ready version exist. However, its trademark ANSI art feel has been emulated in a very production ready BBS software called Synchronet. (https://www.synchro.net/)

What in the world does this have to with a Cyberdeck you ask? Well, with the compute power I’ve packed into this Pelican case being thousands of times more than the machines I had in the 90s, I thought it might be fun to have a Docker container at the ready to run a popup BBS from the case any time I want. All reachable through a modern SSH client.

You know, the world is coming to an end, all forms of communication are down… maybe exactly what you need to pass the time is a LoRa connection, a high gain antenna, and a few friends who want to listen to the Seth Able the Bard in the tavern on LORD?

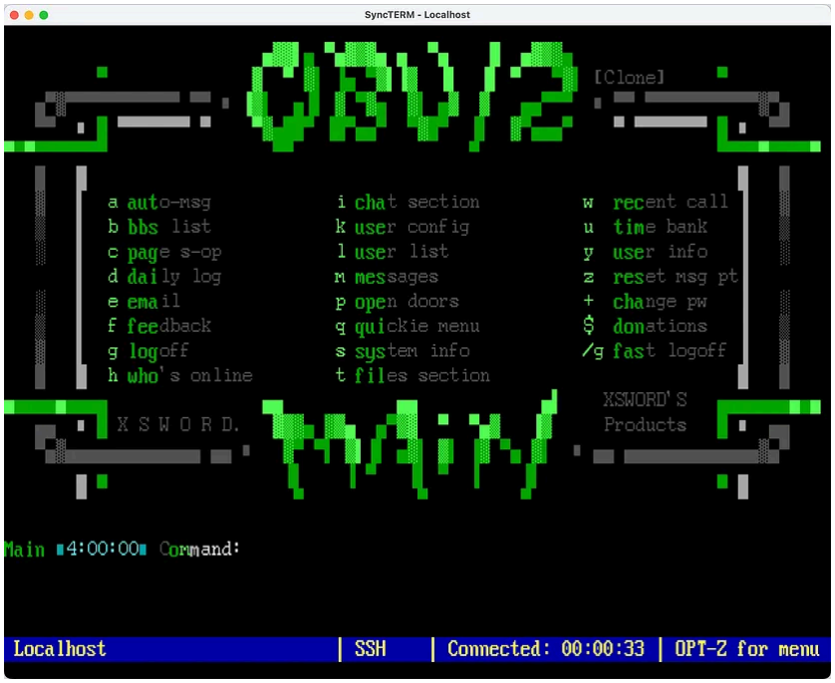
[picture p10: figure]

Synchronet BBS running that all too familiar green menu we all loved.

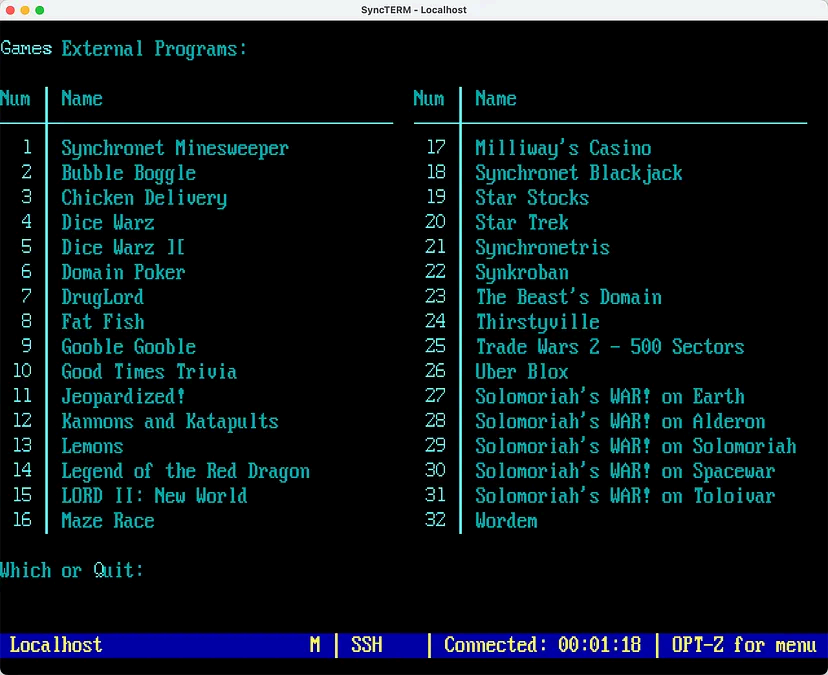
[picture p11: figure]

There’s a list that brings back memories…

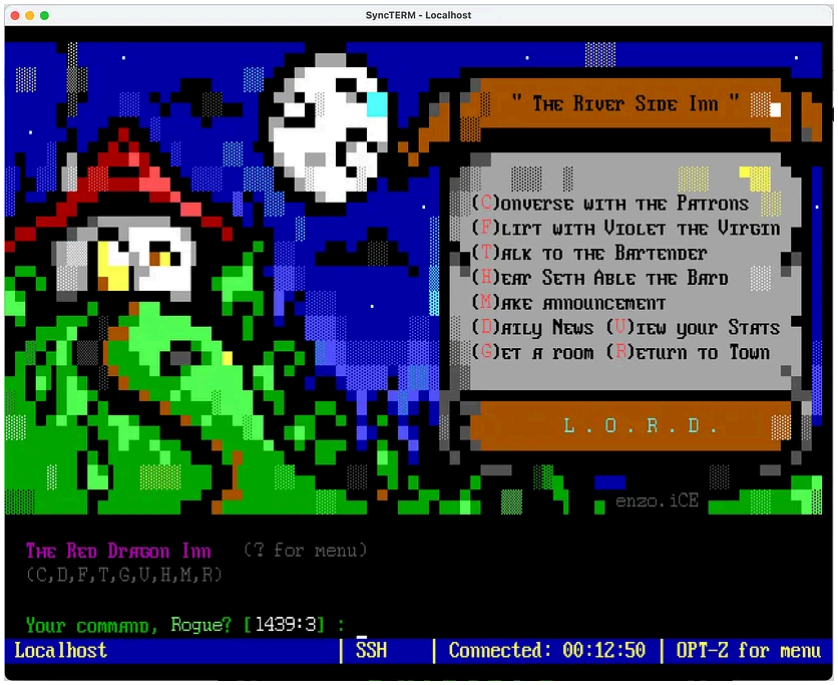
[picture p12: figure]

Let’s just leave poor Violet alone now, ok?

The plan is to use a dynamic DNS service to update my whereabouts whenever the case is powered up so friends can connect. The BBS name? Cyberdeck of course. Hit me up on Fidonet for the new user password. 😳

Currently looking for ANSI artists to commission a custom theme. In the mean time, the Docker configuration is up on GitHub. (https://github.com/jagould2012/cyberdeck)

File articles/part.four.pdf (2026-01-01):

## Cyberdeck: Part Four

medium.com/@jagould2012/cyberdeck-part-three-daf6f7dfc493

As I’ve been waiting for the many Amazon boxes to arrive to start the build, I spent a little time looking through old project boxes to make sure I hadn’t missed anything that would fit nicely in the build. Two new discoveries have been added that I think will be great additions.

PepWave MAX BR1 Mini

With a built-in 4G LTE cellular radio, two Ethernet port switch, and WiFi radio — this will give me a number of options for uplink where available. The WiFi can be configured for Wifi-as-WAN (with an added license), so the device can connect to available Internet and serve it out over the two Ethernet ports to the Raspberry Pi boards. This is particularly helpful as it leaves the AXE3000 WiFi radio I bought available for other purposes (like monitor mode).

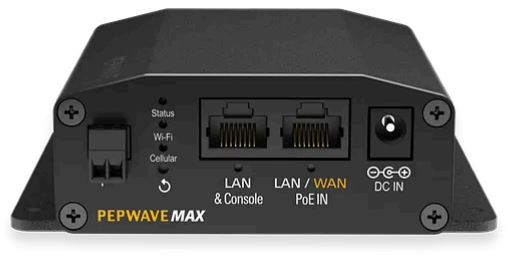
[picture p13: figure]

PepWave MAX BR1 Mini

The device accepts a DC supply of 12–28V DC, which required a slight change in our power design as our main supplies are all 5V (for the LCD displays and Raspberry Pi SBCs). I could have just connected the device to the onboard 24V DC supply, but that would mean the PepWave would only be available when connected to mains.

The power design now includes a third 60W buck boost power supply, this one with a 12V DC output. Using the same family as the 5V supply, it also accepts a wide 9V — 36V DC input (see power supply article). (https://medium.com/@jagould2012/cyberdeck-part-three-b9f26160baa1)

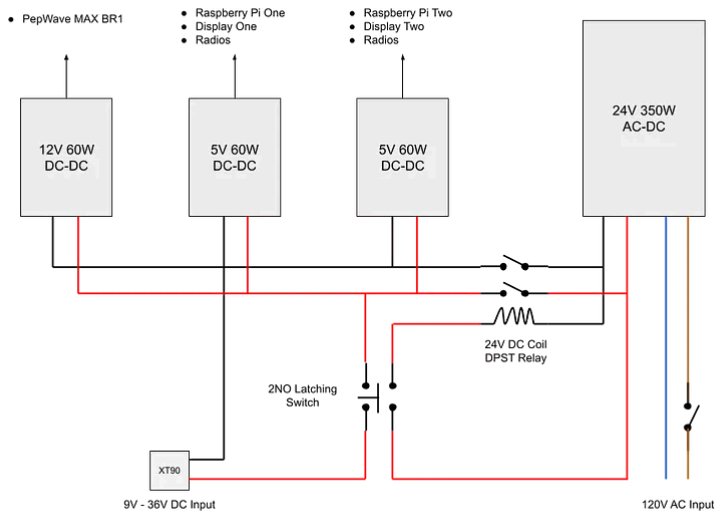
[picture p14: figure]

Addition of a 12V 60W power supply.

60W output is quite a bit more than the PepWave requires, but it will be helpful in the future to have available capacity at both 5V and 12V, all operating on our dual supply design.

Ubertooth One

Another great design from Great Scott Gadgets, the Ubertooth One (https://greatscottgadgets.com/ubertoothone/) provides some great capabilities specifically in the Bluetooth spectrum. It’s an older device thats been retired by the manufacturer, but I remember it being very helpful in the project I originally purchased it for.

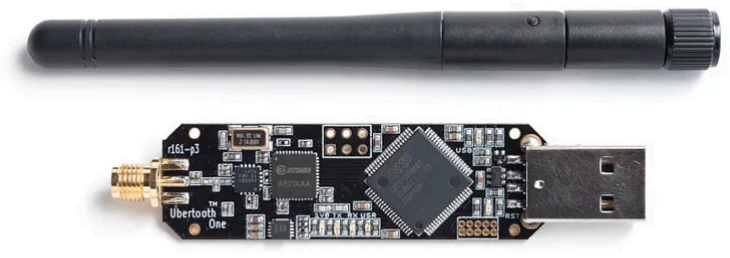
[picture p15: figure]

Great Scott Gadgets Ubertooth One

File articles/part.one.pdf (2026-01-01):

## Cyberdeck: Part One

medium.com/@jagould2012/cyberdeck-part-one-45e778d2b7b9

Over the years I’ve collected all kinds of interesting little radios, from LoRa Meshtastic, to Software Defined Radios (RTL-SDR), and had a few days of fun with each. But over time, most end up on a shelf or in a storage container when I need space on my desk for another project (which is currently a mobile Kubernetes cluster project).

The other day an ad made it into my feed for the Clockwork uConsole (https://www.clockworkpi.com/home-uconsole) that caught my eye. It’s an interesting little handheld device that hosts a Raspberry Pi compute module, a touchscreen, and has an optional board (https://hackergadgets.com/products/uconsole-rtl-sdr-lora-gps-rtc-usb-hub-all-in-one-extension-board) for an SDR. This almost became my next impulse buy gadget, but between the cost of the pieces and the several week lead time, I thought I would do a little more looking around in this “Cyberdeck” world. What else are people building in this space?

Rabbit hole… deep…

Inspired by some pretty cool builds out there, I turned to one of my favorite suppliers of luggage for my diving equipment, Pelican. Beside making complete indestructible cases, they also make some very cool mounting options for projects like this with their Special Application Panel Frames. (https://business.pelican.com/us/en/product/Accessories/1500pf)

With a Pelican 1500 case size in mind, I turned to the good folks at DataPro International who allow you to custom design plates online (https://www.datapro.net/cgi-bin/plate-designer-pro) specifically for the Pelican frames. After a few hours of browsing a variety of LCD screens, mounts, and antennas on Amazon, I started to realize that I didn’t want to invest in a plate with a custom hole in it for a specific size screen, only for it to not be available for replacement or upgrade late, leaving me to buy another custom plate (which can get a bit pricey). I wanted something more configurable that I could change around later and re-use the same plate and case.

Then I remembered another ad I had seen recently for a growing trend in home servers, the 10" format rack. Most of these home servers are single board computer based, and many include small touchscreen LCD displays mounted in the rack.

Perfect.

So, I grabbed my morning coffee, found the specs for the drill pattern, and before long had placed an order for what is basically a 5U 10" format rack in a Pelican case. A few extra holes for SMA bulkheads for antenna, and a power inlet and switch, and we have the beginnings of a pretty great build.

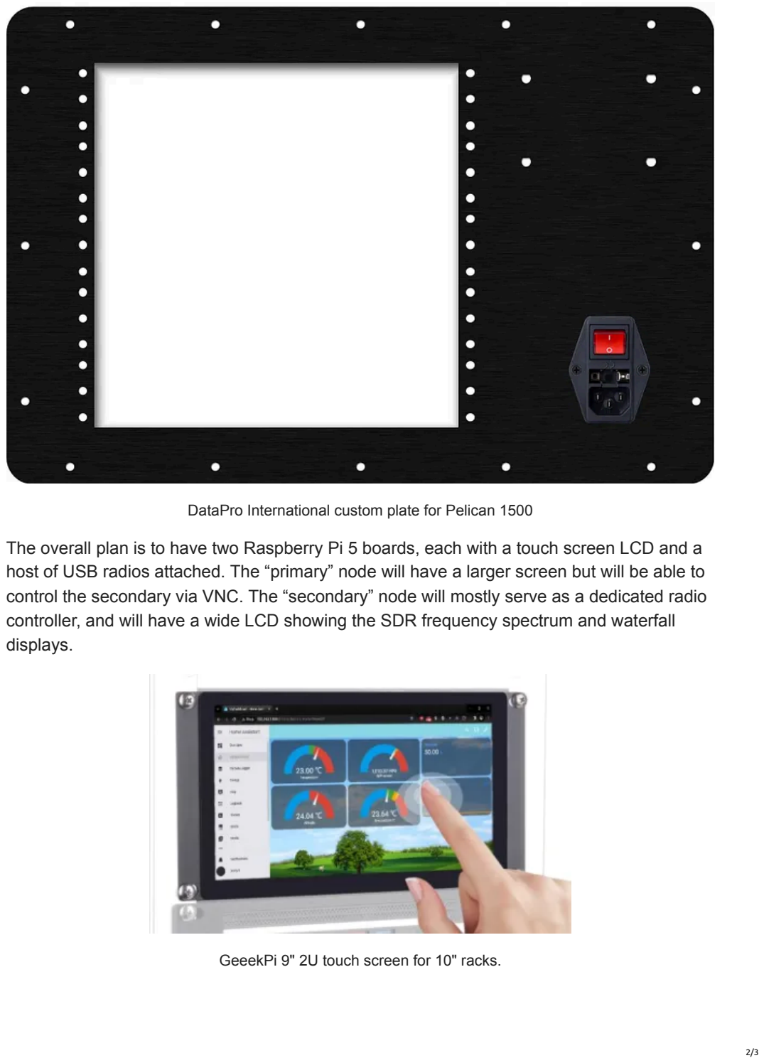
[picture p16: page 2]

DataPro International custom plate for Pelican 1500

The overall plan is to have two Raspberry Pi 5 boards, each with a touch screen LCD and a host of USB radios attached. The “primary” node will have a larger screen but will be able to control the secondary via VNC. The “secondary” node will mostly serve as a dedicated radio controller, and will have a wide LCD showing the SDR frequency spectrum and waterfall displays.

GeeekPi 9" 2U touch screen for 10" racks.

GeeekPi 6.9" 1U touch screen for 10" racks.

Plenty of USB-C power will be supplied by two 60w 5V DC-DC power supplies, each capable of running off of an external 9V — 36V wide range DC input (car battery, Lipo drone batteries, Dewalt power tool batteries, solar panels) or the built-in 24V DC power supply from the mains input, with the flip of a selector switch.

So here’s the bill of materials so far:

Pelican Protector 1500 case ()
Pelican 1500PF frame ()
Two Raspberry Pi 5 with 16GB of memory () GeeekPi 1U mount for Raspberry Pi () GeeekPi 3U 9" LCD display ()
GeeekPi 1U 6.9" LCD display ()
Waveshare SX1262 LoRaWAN module ()
Alfa Network AXE3000 WiFi adapter ()
Two Mean Well RSD-60G-5 DC to DC power supplies () Mean Well LRS-350–24 DC power supply ()
3 position power selector switch ()
XT90 panel mount DC input ()

Stay tuned over the next few weeks for future articles:

Assembling the case
The power supply design (dual inputs) Selecting and configuring the OS (Ubuntu, Kali?) Configuring the applications

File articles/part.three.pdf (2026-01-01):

## Cyberdeck: Part Three

medium.com/@jagould2012/cyberdeck-part-three-b9f26160baa1

A key part of the design is the ability to power the system up just about anywhere. LoRa / Meshtastic and the software defined radios can be used to establish communications during a natural disaster, civil unrest, or any extended power / internet outage.

This requires a design that accepts a variety of power sources:

100VAC — 120VAC and 200–240VAC 50/60Hz mains for normal operation
Wide range DC input of 9V — 36V external sources such as vehicles, solar panels, power tool batteries, etc.

All producing stable and clean 5V DC power for the various USB powered computers, radios, and displays. With two power hungry Raspberry Pi 5 (recommended 5A each), two LCD displays, and a selection of radios, a minimum of 100W of power is needed.

The design includes:

Two 60W DC-DC 5V buck boost power converters. These accept a wide range of DC power and put out a nice clean 5V signal.
A large 350W 24DC power supply that feeds the 5V supplies when operating off of mains. This supply is internationally rated and can run on power anywhere in the world. An external DC input jack for connecting any source. I chose an XT90 connector for durability and because I already own a number of high capacity 4S style 14.8V batteries from a drone project that use this connector. The case will also have an assortment of XT90 cables, including with alligator clips for attaching to car batteries.

One concern when using dual DC inputs is issues that can arise from a common DC ground. While ground sharing is normally ok, it can create ground potential issues when a device is say grounded to a vehicle. To eliminate any possibility of this, the internal DC power supply is disconnected automatically (both 24VDC and ground) from the 5V supplies whenever the selector switch is off or in the external input position. This is done by passing both the +/- of the supply through a DPST relay, and controlling the relay coil with the 24VDC power passed through the selector switch (diagram below).

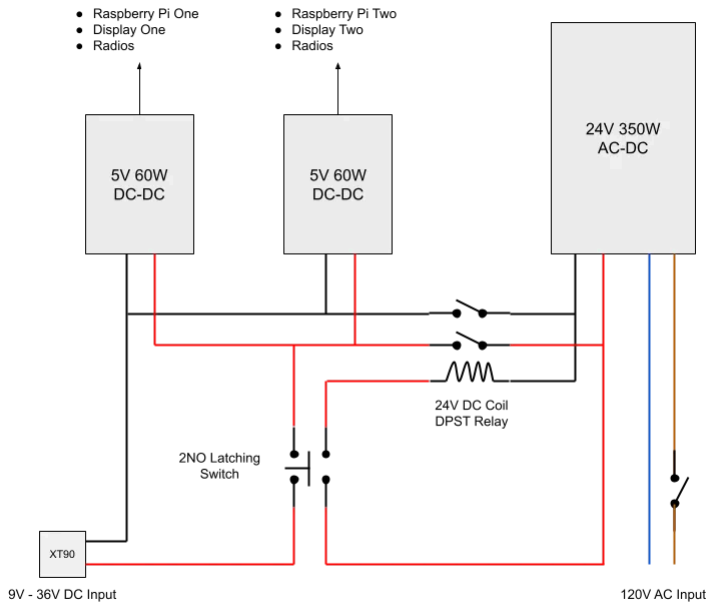
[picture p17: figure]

Ground isolation is achieved with a DPST relay and selector switch.

The whole package is fairly lightweight and fits nicely into the Pelican 1500 case (assembly photos coming in a future article). Perhaps the design is a little over-spec’d for a few Raspberry Pi boards and some USB devices? However, it gives me the ability to bring up the system in any setting, anywhere in the world — regardless of power conditions — and that just seems right for such a capable little piece of kit.

Updated Dec 20, 2025

To accommodate the addition of some new radios that require 12V DC power, and third buck boost power supply was added. See the “More Radios” link below.


Addition of a 12V 60W power supply.

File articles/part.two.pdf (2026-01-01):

## Cyberdeck: Part Two

medium.com/@jagould2012/cyberdeck-part-two-d0d4e60bcab0

As parts start arriving, I continued to research other builds and review the list of radios and devices I plan to include in the initial configuration. One area that particularly interested me was the software defined radio (SDR).

I currently own an RTL-SDR, (https://amzn.to/3Yxtzwq) which is a very capable little USB device that can receive a wide range of frequencies and will be included in the build. However, another SDR that continues to show up in my searches is the HackRF One (https://amzn.to/4s1bvII) from Great Scott Gadgets. It has a few significant advantages over my current radio:

1 MHz—6 GHz frequency range
20 MHz bandwidth
Transmit capability

However, at at cost of $350—$400, I don’t think I could justify spending that much on another SDR. So I gave up on that idea (almost).

Rabbit hole. Even deeper…

It turns out, I’m not the only one who feels this way about the price. I discovered that the HackRF One is actually an open source (https://github.com/greatscottgadgets/hackrf) design, and a fairly large community has grown up around extended the device’s capabilities, which has attracted the attention of a few Chinese manufacturers. One group of developers that particularly interest me is the Mayhem project: (https://github.com/portapack-mayhem/mayhem-firmware)

Extends the HRF board with an LCD screen board and click wheel
Packaged in a more portable handheld case
Custom open source firmware, including a lot of very “interesting” applications (for educational purposes only of course)
Available from Chinese manufacturers for less than $200. One in particular, , which has a very good reputation in the community

So, design update…

The current plan is to mount a Mayhem edition H4M Portapack on the Pelican case custom plate, between the power section and the antenna SMA group (build steps in a future article). I opted for the “Clifford Heath” version, which is an upgraded design by someone in the open source community, that fixes a few problems with the original HRF design. It also swaps a

1/2 few components for higher spec parts, but still stays well below the $200 price point. The Mayhem edition is also very cool looking, printed on a white PCB, and silk screened with the GitHub usernames of the projects top contributors.

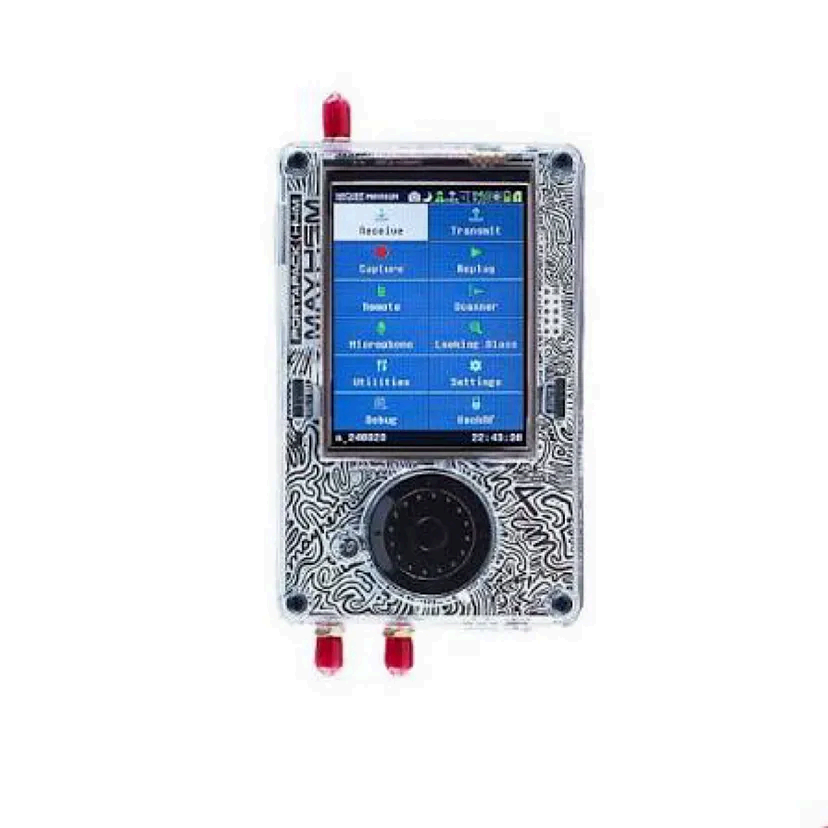
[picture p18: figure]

I’ve also created a GitHub repository (https://github.com/jagould2012/cyberdeck) for the project that will contain:

Configuration files for the various OS and applications
A full bill of materials in csv format, including all the misc screws and cables used in the build

Follow for future articles to see how the whole thing is assembled, and I’ll be adding an article to the series reviewing the Mayhem’s features. In the meantime, check out the first article (https://medium.com/@jagould2012/cyberdeck-part-one-45e778d2b7b9) in the series for an overview of the project.

2/2

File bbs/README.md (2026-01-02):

# Synchronet BBS

Based on: https://wiki.synchro.net/howto:raspbian_install

## Files Included

- `Dockerfile` - Dockerfile for ARM64 Synchronet BBS with DOSEMU2 support
- `docker-compose.yml` - Docker Compose configuration
- `entrypoint.sh` - Startup script that injects environment variables
- `install.sh` - Installation script
- `README.md` - This file

## Quick Start

```bash
# Run the installer
chmod +x install.sh
./install.sh

# The installer will:
# 1. Build the Docker image
# 2. Extract default config files
# 3. Launch scfg for initial configuration
# 4. Sanitize passwords from config files
# 5. Start the container
```

## Environment Variables

The following environment variables can be configured (e.g., in Portainer):

| Variable | Description | Default |
|---|---|---|
| `SYSOP_PASSWORD` | Sysop/admin password | `changeme` |
| `BBS_NAME` | Name of your BBS | `My BBS` |

### How It Works

1. The `install.sh` script removes passwords from config files after running scfg, replacing them with `SET_VIA_ENV`
2. Config files are safe to commit to git with placeholder values
3. At container startup, `entrypoint.sh`:
   - Copies `main.ini` to `/tmp/main.ini`
   - Injects the real password from `SYSOP_PASSWORD` environment variable
   - Uses a bind mount to overlay the modified file over the original
   - The host volume remains untouched with the placeholder value
4. Set the actual password in Portainer or your deployment environment

> **Note:** The container requires `SYS_ADMIN` capability for the bind mount. This is already configured in `docker-compose.yml`.

### Setting in Portainer

1. Go to your stack/container settings
2. Add environment variables:
   ```
   SYSOP_PASSWORD=your_secure_password
   BBS_NAME=Your Awesome BBS
   ```
3. Redeploy the container

### Setting via .env file (local development)

Create a `.env` file (add to .gitignore!):
```bash
SYSOP_PASSWORD=your_secure_password
BBS_NAME=Your Awesome BBS
```

---

## Directory Structure

The official Synchronet installation creates this directory structure:
```
/sbbs/
├── ctrl/     # Configuration files (copied, not symlinked - runtime writable)
├── data/     # User data, messages, etc. (runtime writable)
├── docs/     # Documentation (symlink to repo)
├── exec/     # Executables AND JavaScript runtime files
├── mods/     # Custom modifications
├── node1-4/  # Node directories
├── repo/     # The git repository
├── text/     # Menu files, ANSI art, themes (symlink to repo)
├── web/      # Legacy web interface (symlink to repo)
├── webv4/    # Modern web interface (symlink to repo)
└── xtrn/     # External programs/doors (symlink to repo)
```

## Dockerfile

1. Clones the full repository to `/sbbs/repo`
2. Builds using `make RELEASE=1 NOCAP=1 install` (NOCAP=1 for Docker)
3. Creates symlinks for read-only directories (text, xtrn, web, docs, webv4)
4. Copies ctrl/ (needs to be writable for config changes)
5. Ensures JavaScript files from repo/exec are available
6. Sets proper environment variables including LD_LIBRARY_PATH
7. Sets TERM=ansi-bbs for proper terminal handling
8. Compiles the ansi-bbs terminfo entry
9. Uses entrypoint.sh to inject environment variables at startup

## Building

```bash
./install.sh
```

## Running With Persistent Data

```bash
docker compose up -d
```

## Reconfiguring

```bash
docker exec -it SynchronetBBS /sbbs/exec/scfg
```

## Other Setting

* Disable IPV6

`sbbs.ini`
```
[Global]
Interface=0.0.0.0
```

---

## Theme Install - Cyberdeck

The Cyberdeck theme applies a consistent grayscale color scheme across all BBS screens. Colors used:
- **Bright white** (`\x01h\x01w`) - First letter of words, highlights
- **Gray** (`\x01n\x01w`) - Normal text
- **Dark gray** (`\x01h\x01k`) - Accents, separators
- **Brown/Yellow** (`\x01y`) - Command keys in menus

### Quick Install

```bash
# 1. Apply color theme to system prompts
./update-msg-colors.sh

# 2. Copy ANSI art
./copy-ans.sh

# 3. Copy JS overrides to mods
mkdir -p mods
cp yesnobar.js noyesbar.js mods/

# 4. Restart
docker restart SynchronetBBS
```

### Scripts

| Script | Purpose |
|---|---|
| `update-msg-colors.sh` | Main theme installer - updates attr.ini, text.dat, modopts.ini, text.ini |
| `update-msg-colors.pl` | Converts .msg/.asc file colors (called by update-msg-colors.sh) |
| `update-text-dat.pl` | Converts text.dat system prompt colors (called by update-msg-colors.sh) |
| `generate-text-ini.pl` | Generates ctrl/text.ini for shell prompt colors |
| `copy-ans.sh` | Copies ANSI art from art/ to text/ with proper formatting |

### Custom Files

| File | Purpose |
|---|---|
| `ctrl/attr.ini` | Menu color attributes (mnehigh, mnelow, mnecmd, etc.) |
| `ctrl/text.ini` | Shell prompt color overrides (Main, File, status line) |
| `ctrl/text.dat` | System message colors (modified by script) |
| `ctrl/modopts.ini` | JS module settings like first_caller_msg (modified by script) |
| `mods/yesnobar.js` | Grayscale Yes/No dialog |
| `mods/noyesbar.js` | Grayscale No/Yes dialog |

### copy-ans.sh

Copies ANSI art from `art/` to `text/` with proper Synchronet formatting.

**Setup:**
- Place `.ans` files in `art/` for main screens (e.g., `answer.ans`, `bullseye.ans`)
- Place `.ans` files in `art/menu/` for menu screens (e.g., `main.ans`)
- Place `.ans` files in `art/random/` for random login screens
- Optional: create `file.append.ans` to append content after a pause

**Features:**
- Strips SAUCE metadata from source files
- Truncates files to MAX_ROWS (default 22) to prevent [more] prompt
- Strips trailing blank lines
- Adds clear screen code (Ctrl-A l) at start
- Adds speed control for random login screens

**Usage:**
```bash
./copy-ans.sh              # Uses ./art and ./text as defaults
./copy-ans.sh ./art ./text # Explicit paths
MAX_ROWS=20 ./copy-ans.sh  # Custom row limit
```

### update-msg-colors.sh

Applies the Cyberdeck color scheme to all Synchronet system prompts and menus.

**What it does:**
1. Resets files from Docker image (clean slate)
2. Updates `ctrl/attr.ini` with grayscale theme
3. Modifies `ctrl/modopts.ini` with JS module colors (uses actual Ctrl-A characters)
4. Creates `ctrl/text.ini` for shell prompt overrides
5. Converts `ctrl/text.dat` colors (cyan/blue/green → white, red/magenta → dark gray)
6. Processes all `.msg` and `.asc` files in text/ and text/menu/

**Usage:**
```bash
./update-msg-colors.sh
docker restart SynchronetBBS
```

Backups are saved to `.color-backup-YYYYMMDD-HHMMSS/`.

### Configuring DOS Doors

## Auto Install

Under Doors > Operator > Auto-install New External Programs to configure other doors (Lord, Tradewars).

## Manual Configuration

1. In `sbbs.ini`, ensure `UseDOSemu=true` is set in the `[bbs]` section (the Dockerfile does this automatically)
2. Configure doors in SCFG under External Programs
3. DOS doors use these drive mappings:
   - D: = /sbbs/node1 (or current node)
   - E: = /sbbs/xtrn
   - F: = /sbbs/ctrl
   - G: = /sbbs/data
   - H: = /sbbs/exec

For more details, see: https://wiki.synchro.net/howto:raspbian_install

---

## Key Directories Explained

| Directory | Purpose | Mount as Volume? |
|---|---|---|
| ctrl/ | Config files (sbbs.ini, etc.) | Yes - persists config |
| data/ | User data, messages, files | Yes - persists data |
| text/ | Menus, ANSI art, themes | Optional - if customizing |
| xtrn/ | Doors/external programs | Optional - if adding custom doors |
| mods/ | Custom JavaScript mods | Optional - for customizations |
| exec/ | Binaries + JS runtime | No - part of image |

## Ports

Default port mappings in docker-compose.yml:

| Host Port | Container Port | Service |
|---|---|---|
| 10022 | 22 | SSH (Synchronet's built-in, not system SSH) |

Additional ports (uncomment in docker-compose.yml if needed):
| Port | Service |
|---|---|
| 25 | SMTP |
| 110 | POP3 |
| 119 | NNTP |
| 10023 | 23 | Telnet |
| 10080 | 80 | HTTP Web Interface |
| 10443 | 443 | HTTPS |
| 10513 | 513 | RLogin |
| 10021 | 21 | FTP |

---

## Connecting with SyncTERM

SyncTERM is the recommended terminal for connecting to BBS systems. It properly displays ANSI art and handles door games correctly.

### Download SyncTERM

| Platform | Download |
|---|---|
| **Windows** | https://sourceforge.net/projects/syncterm/files/latest/download |
| **macOS** | https://syncterm.bbsdev.net/ (look for macOS build) |
| **Linux** | `sudo apt install syncterm` or download from https://syncterm.bbsdev.net/ |

### Connect to Your BBS

1. Open SyncTERM
2. Press **D** for Dialing Directory, then **E** to edit/add entry
3. Create a new entry:
   - **Name:** My BBS
   - **Address:** `localhost:10022` (or your server's IP)
   - **Connection Type:** SSH
   - **Screen Mode:** 80x25
4. Press **Escape** to save, select your entry and press **Enter**

For new users, enter `new` as the SSH username and dont enter a password.

### Tips
- Press **Alt+Enter** for fullscreen
- Use **80x25** screen mode for door games
- SyncTERM supports ANSI music!

---

## Alternative Terminals

| Terminal | Platform | URL |
|---|---|-----|
| **SyncTERM** | Win/Mac/Linux | https://syncterm.bbsdev.net/ |
| **NetRunner** | Windows | https://www.mysticbbs.com/downloads.html |
| **EtherTerm** | Win/Mac/Linux | https://github.com/M-griffin/EtherTerm |
| **Qodem** | Linux | http://qodem.sourceforge.net/ |

---

## Troubleshooting

### "DOS programs not supported" error
- Ensure `UseDOSemu=true` in `/sbbs/ctrl/sbbs.ini` under `[bbs]`
- DOSEMU2 must be installed for DOS doors

### Missing themes/menus
- Check that `/sbbs/text` is properly symlinked to `/sbbs/repo/text`
- Run `ls -la /sbbs/text/` to verify contents

### Doors not showing
- Check that `/sbbs/xtrn` is properly symlinked to `/sbbs/repo/xtrn`
- Configure doors in SCFG → External Programs

### Libraries not found
- Ensure `LD_LIBRARY_PATH` includes `/sbbs/exec`
- Check that `.so` files exist in `/sbbs/exec/`

### Container keeps restarting
- Run scfg to generate initial configuration: `./install.sh`
- Check logs: `docker logs SynchronetBBS`

### SSH key errors
- The entrypoint script handles SSH key generation
- If issues persist: `docker exec SynchronetBBS rm -f /sbbs/ctrl/cryptlib.key` then restart

---

## Security Notes

- **Never commit real passwords to git** - The install script sanitizes passwords automatically
- **Use environment variables** for sensitive data (SYSOP_PASSWORD)
- **The .gitignore** excludes sensitive files like `*.key`, `*.pem`, and data directories
- **Set strong passwords** in your production environment (Portainer, etc.)

---

## References

- Synchronet Wiki: http://wiki.synchro.net
- Raspberry Pi Install: https://wiki.synchro.net/howto:raspbian_install
- UNIX Installation: http://wiki.synchro.net/install:nix
- Prerequisites: http://wiki.synchro.net/install:nix:prerequisites

---

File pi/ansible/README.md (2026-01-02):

# Ansible Raspberry Pi Setup

Ansible playbooks for automating Raspberry Pi Kali Linux setup and configuration, including SDR software.

## Prerequisites

### On your control machine (Mac/Linux):

1. Install Ansible:
   ```bash
   # macOS
   brew install ansible
   
   # Ubuntu/Debian
   sudo apt install ansible
   
   # pip
   pip install ansible
   ```

2. **Build SDRAngel package first** (if you want SDRAngel):
   ```bash
   cd ../sdrangel
   ./build.sh
   ```
   This builds the arm64 `.deb` on your Mac and copies it to `ansible/files/`. See `../sdrangel/README.md` for details.

3. **Configure BBS locally first** (if deploying Synchronet BBS):
   ```bash
   cd ../bbs
   ./install.sh           # Configure BBS (interactive - set up name, settings)
   ./update-msg-colors.sh # Apply Cyberdeck grayscale theme
   ./copy-ans.sh          # Copy ANSI art to text/
   ```

4. **Build and export BBS Docker image** (required before deployment):
   ```bash
   cd ../bbs
   docker compose build
   docker save bbs-synchronet:latest | gzip > bbs-synchronet.tar.gz
   ```
   This builds the amd64 image locally (much faster than building under QEMU on ARM) and exports it for distribution to target hosts. The resulting file is ~300-500MB.

   The ansible playbook copies the pre-configured `ctrl/`, `text/`, and `xtrn/` directories plus the Docker image to the target hosts.

### On target hosts:

1. Ensure SSH is enabled. If not, connect via console and run:
   ```bash
   sudo apt update
   sudo apt install -y openssh-server
   sudo systemctl enable ssh
   sudo systemctl start ssh
   ```

2. Copy SSH keys from your control machine:
   ```bash
   ssh-copy-id jonathan@cyberdeck-pi1.local
   ssh-copy-id jonathan@cyberdeck-pi2.local
   ssh-copy-id parallels@10.211.55.5
   ```

## Quick Start

1. Test connectivity:
   ```bash
   ansible all -m ping
   ```

2. Run the full setup on all hosts:
   ```bash
   ansible-playbook site.yml -K
   ```

3. Or run on specific hosts:
   ```bash
   # Just the test VM (include localhost for BBS tarball creation)
   ansible-playbook site.yml --limit "localhost,test-vm" -K

   # Just physical Pis
   ansible-playbook site.yml --limit "localhost,pi" -K

   # Single host
   ansible-playbook site.yml --limit "localhost,cyberdeck-pi1" -K
   ```

## Directory Structure

```
project/
├── bbs/                     # Synchronet BBS (configure locally first)
│   ├── Dockerfile
│   ├── docker-compose.yml
│   ├── install.sh           # Run first - interactive setup
│   ├── update-msg-colors.sh # Run second - apply theme
│   ├── copy-ans.sh          # Run third - copy ANSI art
│   ├── bbs-synchronet.tar.gz # Docker image (created by docker save)
│   ├── ctrl/                # Generated config (after install.sh)
│   ├── text/                # ANSI screens and menus
│   └── xtrn/                # External programs/doors
├── sdrangel/                # SDRAngel .deb builder (run this first)
│   ├── Dockerfile
│   ├── build.sh
│   └── README.md
└── ansible/                 # This directory
    ├── ansible.cfg
    ├── inventory.yml
    ├── site.yml
    ├── files/
    │   └── sdrangel_arm64.deb  # Created by ../sdrangel/build.sh
    ├── group_vars/
    ├── host_vars/
    └── playbooks/
```

## Sudo Password

If a host requires a sudo password, add `-K` (or `--ask-become-pass`):
```bash
ansible-playbook site.yml -K
```

To configure passwordless sudo on a host, connect via SSH and run:
```bash
echo "$USER ALL=(ALL) NOPASSWD: ALL" | sudo tee /etc/sudoers.d/$USER
```

## Inventory Groups

| Group | Description | Hosts |
|---|---|---|
| `raspberry_pis` | All hosts | cyberdeck-pi1, cyberdeck-pi2, test-vm |
| `pi` | Physical Raspberry Pis | cyberdeck-pi1, cyberdeck-pi2 |
| `vm` | Virtual machines | test-vm |

Hardware-specific tasks (HDMI, fan, boot config) only run on the `pi` group.

## Hosts

| Host | Group | User | Hostname | Notes |
|---|---|---|---|---|
| cyberdeck-pi1 | pi | jonathan | cyberdeck-pi1 | |
| cyberdeck-pi2 | pi | jonathan | cyberdeck-pi2 | WiFi MAC override |
| test-vm | vm | parallels | cyberdeck-testvm | Skips hardware tasks |

## SDR Software

| Software | Install Method | Notes |
|---|---|---|
| SDR++ | Prebuilt `.deb` from GitHub | Fast install |
| URH | pip install | Universal Radio Hacker |
| SDRAngel | Local `.deb` from `../sdrangel/` | Build on Mac first |

## Individual Playbooks

Run specific playbooks as needed:

```bash
# Boot configuration (pi group only)
ansible-playbook playbooks/boot-config.yml

# Network setup
ansible-playbook playbooks/network-setup.yml

# Set hostname
ansible-playbook playbooks/hostname.yml

# Docker installation
ansible-playbook playbooks/docker-install.yml -K

# Portainer (Docker web UI)
ansible-playbook playbooks/portainer.yml -K

# SDR software
ansible-playbook playbooks/sdr-base.yml -K
ansible-playbook playbooks/sdrpp.yml -K
ansible-playbook playbooks/urh.yml -K
ansible-playbook playbooks/sdrangel.yml -K

# Custom menu categories
ansible-playbook playbooks/menu.yml -K

# Synchronet BBS (requires local setup first - see Prerequisites)
# NOTE: Must include localhost in limit for tarball creation
ansible-playbook playbooks/bbs.yml -K --limit "localhost,test-vm"
ansible-playbook playbooks/bbs.yml -K --limit "localhost,pi"
ansible-playbook playbooks/bbs.yml -K  # All hosts

# Reboot hosts
ansible-playbook playbooks/reboot.yml --limit test-vm
```

### BBS Deployment Note

The BBS deployment requires two things before running the playbook:

1. **Configure the BBS locally** (interactive setup):
   ```bash
   cd ../bbs
   ./install.sh           # Configure BBS settings
   ./update-msg-colors.sh # Apply Cyberdeck theme
   ./copy-ans.sh          # Copy ANSI art
   ```

2. **Build and export the Docker image**:
   ```bash
   cd ../bbs
   docker compose build
   docker save bbs-synchronet:latest | gzip > bbs-synchronet.tar.gz
   ```

The `bbs.yml` playbook requires `localhost` to be included in the limit because it creates a tarball locally before copying to remote hosts. Always use one of these patterns:

```bash
# Deploy to specific host (include localhost)
ansible-playbook playbooks/bbs.yml -K --limit "localhost,test-vm"

# Deploy to all Pis (include localhost)
ansible-playbook playbooks/bbs.yml -K --limit "localhost,pi"

# Deploy to all hosts (no limit needed)
ansible-playbook playbooks/bbs.yml -K
```

**Why pre-build the image?** The BBS runs in an amd64 container (for Synchronet compatibility). Building under QEMU emulation on ARM hosts takes 30-60+ minutes. Pre-building on your Mac/x86 machine takes ~5 minutes and the image is distributed to all hosts.

## What Gets Configured

| Component | Hosts | Description |
|---|---|---|
| Hostname | all | Set via hostnamectl, updated in /etc/hosts |
| HDMI | pi only | Force hotplug, disable blanking |
| Fan | pi only | GPIO fan overlay enabled |
| USB | pi only | Max current enabled |
| Console | pi only | Blanking disabled (kernel cmdline) |
| Sleep | all | All sleep targets masked |
| Network | all | NetworkManager as renderer |
| mDNS | all | Avahi daemon enabled |
| SSH | all | Host keys generated if missing |
| Docker | all | CE + Compose plugin installed |
| Portainer | all | Docker web UI at https://localhost:9443 |
| SDR Base | all | Dependencies, udev rules for RTL-SDR/HackRF/Airspy |
| SDR++ | all | SDR receiver software |
| URH | all | Protocol analyzer |
| SDRAngel | all | Full-featured SDR suite (requires `.deb`) |
| Menu | all | Custom Kali menu categories (17-SDR, 18-Docker) |
| BBS | pi1, test-vm | Synchronet BBS (container runs); pi2 staged only |

## Customization

### Adding a new host

Edit `inventory.yml` and add to the appropriate group:

```yaml
pi:
  hosts:
    cyberdeck-pi3:
      ansible_host: cyberdeck-pi3.local
      custom_hostname: cyberdeck-pi3
```

### Adding a WiFi MAC override

Add `wifi_mac_override` to the host in `inventory.yml`:

```yaml
cyberdeck-pi2:
  ansible_host: cyberdeck-pi2.local
  custom_hostname: cyberdeck-pi2
  wifi_mac_override: "DE:AD:BE:EF:CA:FE"
```

## Troubleshooting

### Connection Issues
```bash
# Test SSH connection
ssh jonathan@cyberdeck-pi1.local

# Test Ansible connectivity
ansible all -m ping -vvv
```

### Check Playbook Syntax
```bash
ansible-playbook site.yml --syntax-check
```

### Dry Run
```bash
ansible-playbook site.yml --check --diff
```

### Verbose Output
```bash
ansible-playbook site.yml -vvv
```

### SDRAngel not installing
Make sure you built the `.deb` first:
```bash
cd ../sdrangel
./build.sh
```

## Notes

- Playbooks are idempotent - safe to run multiple times
- SSH keys only generated if they don't exist
- Docker group membership requires logout/login to take effect
- A reboot may be required after boot configuration changes on Pis
- SDRAngel requires building the `.deb` first (see `../sdrangel/README.md`)

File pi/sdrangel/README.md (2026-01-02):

# SDRAngel ARM64 Debian Package Builder

Builds SDRAngel as a `.deb` package for Raspberry Pi (arm64/aarch64) using Docker on Apple Silicon Mac.

## Why?

SDRAngel doesn't provide prebuilt arm64 packages. Building from source on a Raspberry Pi takes 1-2+ hours. This Docker build runs on your Mac (much faster) and produces a `.deb` that installs in seconds.

## Prerequisites

- Apple Silicon Mac (M1/M2/M3)
- Docker Desktop installed and running
- ~10GB free disk space

## Usage

```bash
./build.sh
```

This will:
1. Build the Docker image (~30-60 minutes first time)
2. Compile SDRAngel and all dependencies
3. Package everything into a `.deb` file
4. Copy the `.deb` to `../ansible/files/sdrangel_arm64.deb`

## Output

- `output/sdrangel_<version>_arm64.deb` - The built package
- `../ansible/files/sdrangel_arm64.deb` - Copy for Ansible deployment

## Manual Installation

If you want to install manually without Ansible:

```bash
scp output/sdrangel_*.deb user@raspberry-pi:~/
ssh user@raspberry-pi 'sudo apt install -f ./sdrangel_*.deb'
```

## With Ansible

After building, deploy to all hosts:

```bash
cd ../ansible
ansible-playbook site.yml -K
```

## What's Included

The package includes SDRAngel and these bundled libraries:
- cm256cc (forward error correction)
- mbelib (voice codec)
- serialDV (DV serial interface)
- dsdcc (digital speech decoder)
- codec2 (voice codec)
- sgp4 (satellite tracking)
- libsigmf (signal metadata)

## Supported SDR Hardware

- RTL-SDR
- HackRF
- Airspy / Airspy HF+
- LimeSDR
- BladeRF
- PlutoSDR
- USRP (via SoapySDR)

## Rebuilding

To rebuild after SDRAngel updates:

```bash
# Remove old image to force fresh build
docker rmi sdrangel-builder

# Build again
./build.sh
```

## Troubleshooting

### Build fails with memory error
Docker Desktop may need more memory. Go to Docker Desktop → Settings → Resources and increase memory to 8GB+.

### Build takes too long
First build downloads and compiles everything (~30-60 min). Subsequent builds with cache are faster.

### Package won't install on Pi
Ensure the Pi is running Debian Bookworm (12) arm64. Check dependencies:
```bash
sudo apt update
sudo apt install -f
```

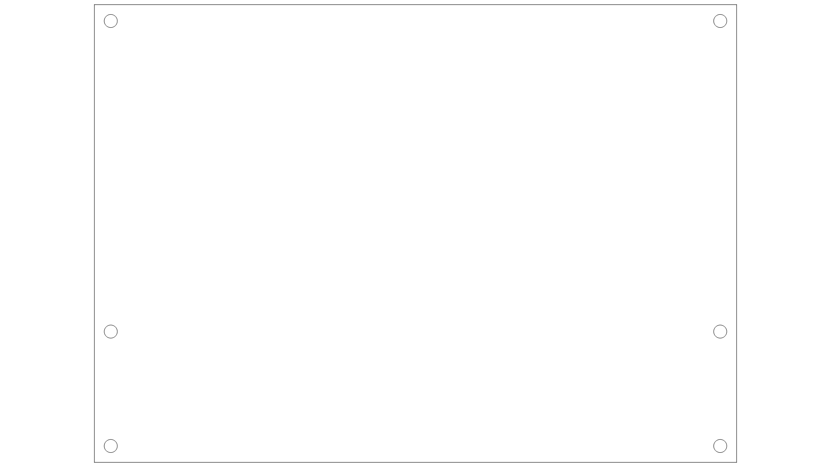
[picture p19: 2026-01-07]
images/usb_drawing.png

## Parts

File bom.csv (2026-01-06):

Quantity | Description | Each | Total | Link | Notes
 | Computers
2 | Raspberry Pi 5 16GB Single Board Computers | $172.99 | $345.98 | https://www.amazon.com/dp/B0DY7MWDF9?linkId=0729d799dd504df3d4454b081bc47bf8&language=en_US | 16GB version to allow for Kubernetes and containers
2 | Patriot M.2 PCIe NVME flash - 256GB | $56.99 | $113.98 | https://www.amazon.com/dp/B082BWY2C2?linkId=7b7f5fd9b6ba912347646656cbd5a0a8&language=en_US | Must be NVME, not SATA
1 | GeeekPi 3U 9" LCD display | $119.99 | $119.99 | https://www.amazon.com/dp/B0FZQGN2FS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
1 | GeeekPi 1U 6.9" LCD display | $89.99 | $89.99 | https://www.amazon.com/dp/B0G337KQS6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
1 | BotBlox Gigabit Ethernet Switch | $128.00 | $128.00 | https://botblox.io/products/gigablox-small-gigabit-switch | Necessary if you want Gigabit between Raspberry Pi SBCs
1 | Keyboard with Touchpad | $65.15 | $65.15 | https://amzn.to/456Uwe9
 | Radios
1 | Waveshare SX1262 LoRaWAN module | $35.99 | $35.99 | https://www.amazon.com/dp/B0C61VK6WQ?linkId=bf6145f00626d97987aac0f0b1e21b07&language=en_US
1 | Alfa Network AXE3000 WiFi adapter | $76.99 | $76.99 | https://www.amazon.com/dp/B0BY8GMW32?linkId=b222d3e9adbca0991b7ad75ab9622bba&language=en_US
1 | Clifford Heath HackRF One with Mayhem Signature-Edition Portapack H4M | $185.00 | $185.00 | https://opensourcesdrlab.com/products/clifford-heath-hackrf-one-with-portapack-h4m?VariantsId=10177
1 | RTL-SDR Blog V4 R828D RTL2832U Software Defined Radio | 49.95 | $49.95 | https://www.amazon.com/RTL-SDR-Blog-RTL2832U-Software-Defined/dp/B0CD7558GT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
1 | HackRF One clock module | $5.51 | $5.51 | https://opensourcesdrlab.com/products/external-high-precision-tcxo-clock-module-ppm01-for-hackrf
1 | Great Scott Gadgets Ubertooth One | $125.00 | $125.00 | https://greatscottgadgets.com/ubertoothone/ | Unfortunately retired
1 | PepWave MAX BR1 Mini | $399.00 | $399.00 | https://www.amazon.com/Peplink-Redundant-Include-PrimeCare-MAX-BR1-MINI-LTEA-US-T-PRM/dp/B0BJZS95VC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
1 | PepWave Wifi-as-WAN license | $100.00 | $100.00 | https://mobilemusthave.com/products/max-br1-mini-wired-wan-wifi-as-wan-license-upgrade
 | Power
2 | Mean Well RSD-60G-5 DC to DC power supplies | $50.57 | $101.14 | https://www.amazon.com/dp/B07BTK94W2?linkId=4942f2dda7032ff47ff2c3d6e985c77a&language=en_US
1 | Mean Well RSD-60G-12 DC to DC power supplies | $43.97 | $43.97 | https://www.amazon.com/dp/B0748MLBYJ?linkId=7f7d304ba9be40efec150acd49fa43d6&language=en_US
1 | Mean Well LRS-350–24 DC power supply | $35.97 | $35.97 | https://www.amazon.com/dp/B07VRK86SP?linkId=80ef2383d3ab9bfcb08e79d1e220cccd&language=en_US
1 | Apiele 3 position power selector switch | $14.99 | $14.99 | https://www.amazon.com/dp/B07L5C96K9?linkId=33712ead656fab04a347692eac6e55f0&language=en_US
1 | XT90 panel mount DC input | $14.99 | $14.99 | https://www.amazon.com/dp/B0F6YH61JR?linkId=da2184e3afff963d3b9a519059c251fd&language=en_US
1 | 24VDC 6 pin DPST NO relay | $11.51 | $11.51 | https://www.amazon.com/dp/B0D9RTDQ5H?linkId=9d9cccd13d026f527c9b52b82b7f68d0&language=en_US
 | Case
1 | Pelican Protector 1500 case | $157.56 | $157.56 | https://www.amazon.com/dp/B0000DYV9H?linkId=000cd1fb6d050174b3d86df524f25cd5&language=en_US
1 | Pelican 1500PF frame | $22.95 | $22.95 | https://www.bhphotovideo.com/c/product/688576-REG/Pelican_1500_300_110_1500PF_Special_Application_Panel.html
1 | GeeekPi 1U mount for Raspberry Pi | $53.99 | $53.99 | https://www.amazon.com/dp/B0F7XBVV4D?linkId=b8ac03b1ecf525a0adfd638ab41b795e&language=en_US
1 | Custom aluminum plate for Pelican 1500 | $273.33 | $273.33 | https://www.datapro.net/cgi-bin/plate-designer-pro
 | Misc Hardware, Cables, and Accessories
1 | 1' Female Bulkhead Angle to N Female Pigtail Jumper | $19.87 | $19.87 | https://www.amazon.com/dp/B01HLDSGKE?linkId=f43e39c693549ec98d326b4fad785156&language=en_US | Low profile right angle panel mount for LoRa
1 | Ipex-1 to N Male cable | $16.82 | $16.82 | https://www.amazon.com/dp/B07CR866LX?linkId=a951e02d28a61ffb8e1ec5ac5ca9065a&language=en_US | Waveshare LoRa to N connector
1 | Ipex-1 to RP-SMA cable | $6.99 | $6.99 | https://www.amazon.com/dp/B0CSSPJ8S2?linkId=438d4e2894662c1cff2a462ebd954d1e&language=en_US | For LoRa
2 | RPI-SMA 12" extension cable - 2 pack | $6.99 | $13.98 | https://www.amazon.com/dp/B07MT3VZXZ?linkId=0a91d0981ef509d0fd28ccbb86958586&language=en_US | For AXE3000 WiFi antenna
2 | SMA 12" extension cable - 2 pack | $7.49 | $14.98 | https://www.amazon.com/dp/B08139CQLG?linkId=08997393fe479e61210564a2a0ecdeac&language=en_US | For RTL-SDR antenna
1 | SMA right angle adapter - 4 pack | $7.58 | $7.58 | https://www.amazon.com/dp/B07YW3M4GB?linkId=eca363638807b23059ca236a42444385&language=en_US
2 | ANT 500 antenna | $34.95 | $69.90 | https://www.amazon.com/dp/B01CQYZJV2?linkId=e2eaf07828a5be26dfec1e001170f75b&language=en_US | For RTL-SDR and HackRF One
1 | Meshtasic 5dBi antenna | $13.99 | $13.99 | https://www.amazon.com/dp/B0FT8HKKBN?linkId=3840764c16c918d228075aa9fc518fd6&language=en_US | For LoRa
1 | XT90 extension cable | $21.84 | $21.84 | https://www.amazon.com/dp/B0BWYTGMJH?linkId=4f4cdd02279c4f3be6feb8295d74396a&language=en_US
1 | XT90 alligator clamps | $12.99 | $12.99 | https://www.amazon.com/dp/B0BJ8VXTWR?linkId=fc10867998fdfe6c6c3cf3c75bfa1f27&language=en_US
1 | Heat shrink tubing | $13.99 | $13.99 | https://www.amazon.com/dp/B0BVVMCY86?linkId=2e46068b8e6c4abb1e24180654371b31&language=en_US
1 | Heat shrink terminal kit | $24.99 | $24.99 | https://www.amazon.com/dp/B0C2CBM2YS?linkId=9877c2b1b1108b66da7233dfbe5a4588&language=en_US | Used for larger gauge connections to power supplies
1 | Ferrule crimping kit | $22.98 | $22.98 | https://www.amazon.com/dp/B07PJK2VNT?linkId=d0296b791db320e885a5cbd558e99e0b&language=en_US | Used on all small gauge power wires to terminal blocks
1 | 18 Gauge Automotive Primary Wire | $34.95 | $34.95 | https://www.amazon.com/dp/B075X3GM4H?linkId=d6a169070c2cd6730b9875b40cf228ae&language=en_US
1 | Screw terminal barrier strips | $9.99 | $9.99 | https://www.amazon.com/dp/B0D7VRSH1G?linkId=ef79e244e0a82d01c300dff6fcec04e0&language=en_US | 5V power distribution
1 | USB-C pigtail power cables - 5 pack | $9.99 | $9.99 | https://www.amazon.com/dp/B0BFHXWCS9?linkId=5a9b90fdd67263b50550c6f52fc52b03&language=en_US
1 | 90 Degree DC Power Pigtails Cable, Right Angle DC 5.5mm x 2.5mm | $9.99 | $9.99 | https://www.amazon.com/dp/B0B6HSJRVH?linkId=02bf9384a51607daf7369dfebd27d566&language=en_US | USB hubs
1 | Right and left angle USB extension - pair | $7.99 | $7.99 | https://www.amazon.com/dp/B0793P8XJK?linkId=e8e6c236726e3d53504d852c3f57c5dc&language=en_US | Bring one USB 3.0 port to rear of plate
2 | Coolgear USB 3.2 Powered Hub | $54.95 | $109.90 | https://www.amazon.com/dp/B07G7GP15C?linkId=47bd1e7921d55b1ff99a18a17ed2fc55&language=en_US
2 | Waveshare USB to 2.5Gb Ethernet | $25.99 | $51.98 | https://www.amazon.com/dp/B0D8139N3Z?linkId=616c34a77fc85ccaaefd3e0c492448e2&language=en_US
1 | 1' USB-C to USB A - 5 pack | $8.49 | $8.49 | https://www.amazon.com/dp/B08PXWYKTB?linkId=b4dde1596bad16d339235b70a56b5735&language=en_US | Touch screen connection to Pi USB
1 | 1' USB C flexible cable to USB A | $8.99 | $8.99 | https://www.amazon.com/dp/B0DQS9WR4W?linkId=cee9ec96c272ee831084b332d35c3d24&language=en_US | HackRF One
1 | Right Angle USB C Male to Male Adapter, 90 Degree Type-C to USB A Cable | $11.99 | $11.99 | https://www.amazon.com/dp/B0DCZF24F9?linkId=a8077f041945c77d27396a72c5800c71&language=en_US | Touchscreen control to USB hub(s)
1 | 90 Degree USB Type C Cable, Down Angle .25m | $8.98 | $8.98 | https://www.amazon.com/dp/B0BVYPKYW7?linkId=23b64f1632bdca94c0b7987d16b3d258&language=en_US | AXE3000 to USB hub
1 | 1' USB SuperSpeed Cable, A Right to B Right | $8.09 | $8.09 | https://www.amazon.com/dp/B07YBQTSG6?linkId=eb4d54f2ca3f985d2f67b06a600eee0b&language=en_US | USB hub to Pi
1 | 1' USB SuperSpeed Cable, A Left to B Right | $8.09 | $8.09 | https://www.amazon.com/dp/B07SR71Q67?linkId=ae3f591a806c82cde7fa02b47e764d67&language=en_US | USB hub to Pi
1 | Micro HDMI to HDMI 1' Angle Up - 2 pack | $10.29 | $10.29 | https://www.amazon.com/dp/B07DZY2D4D?linkId=a902bb0f5837d3c0dafbdda1832de5d4&language=en_US
1 | Micro HDMI to HDMI 1' Angle Down - 2 pack | $10.29 | $10.29 | https://www.amazon.com/dp/B07FT1Z3PM?linkId=20cb610c81bcf0546a5e8f187c6e658f&language=en_US
1 | ML1220 rechargeable battery | $11.99 | $11.99 | https://www.amazon.com/dp/B088KT9HB9?linkId=9cfda5ba75d47e04493bda0ed495a981&language=en_US | For Waveshare LoRa radio
1 | Assorted M3 button head screws | $8.99 | $8.99 | https://www.amazon.com/dp/B0D5YYH5ZZ?linkId=f354e612ee2c74fac6f0b3996b4262c9&language=en_US
1 | Assorted M3 standoff kit | $7.99 | $7.99 | https://www.amazon.com/dp/B0F297R23T?linkId=38ef20a6e39a8115416d2fa35d6c8a26&language=en_US
1 | 10-32 rack screws | $8.99 | $8.99 | https://www.amazon.com/dp/B0D5HZ63Y9?linkId=04b6702c01b9d75971e3d1ab6ecfede7&language=en_US
1 | 10-32 lock nuts | $7.55 | $7.55 | https://www.amazon.com/dp/B0F8H5QM28?linkId=7ee86ae5b803837a83192ced3454be49&language=en_US
10 | Threaded Standoff - 2" x 5/16" 10-32 | $1.78 | $17.80 | https://www.mcmaster.com/products/91780a261/
1 | 1/8" ABS plastic sheet 8" x 12" - 2 pack | $11.54 | $11.54 | https://www.amazon.com/dp/B0FJFFH7Z9?linkId=1029d95ab8f9d28ab42d2653db07312e&language=en_US | Custom mounting plates behind aluminum plate
1 | iCraft 1/2" x 1/8" 3D foam tape | $24.17 | $24.17 | https://www.amazon.com/iCraft-5611-Jumbo-Rolls-Black/dp/B093Y43FGF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 | For mounting power components to ABS panels
2 | Neoprene Case | $7.99 | $15.98 | https://www.amazon.com/dp/B01JZ3NEM8?linkId=80bd015303bdc9a928e0defa96a9a1ae&language=en_US | For antenna storage
1 | Left-angle IEC power cable | $9.13 | $9.13 | https://www.amazon.com/dp/B003MGB1EI?linkId=c640d6844eaec2f8ba6b8de4bc8c366d&language=en_US
1 | Adhesive neoprene sheets | $12.99 | $12.99 | https://www.amazon.com/dp/B08P1XQMQH?linkId=6299576ea2492a4487798448a1b6fef9&language=en_US | Lining for case lid to protect keyboard
1 | Neoprene foam | $9.55 | $9.55 | https://www.amazon.com/dp/B09TXGTD1B?linkId=9bd1273f77f26a978f2a5cf1326310af&language=en_US | Protective sheet between keyboard and screens
 |  |  | $3,288.50

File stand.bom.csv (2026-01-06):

Quantity | Description | Each | Total |  | Link | Notes
2 | Inline Pivot for 1" Single Rail | $29.20 | $58.40 | 47065T191 | https://www.mcmaster.com/catalog/47065T191
2 | Single Four Slot Rail, Silver, 1" High x 1" Wide, Solid, 12 in. length | $9.48 | $18.96 | 47065T801 | https://www.mcmaster.com/catalog/47065T801 | Custom cut to 12"
2 | Single Inline 2-Slot Rail, Silver, 1" High x 1" Wide, Solid, 2 in. length | $1.00 | $2.00 | 47065T848 | https://www.mcmaster.com/catalog/47065T848 | Custom cut to 2"
6 | End Cap for 1" High Single Rail, Black | $2.18 | $13.08 | 3136N2 | https://www.mcmaster.com/catalog/3136N2
1 | Antislip Cover for 1" High Single Rail, 6 Feet Long, Black | $19.01 | $19.01 | 47065T362 | https://www.mcmaster.com/catalog/47065T362 | Cut to two 11" pieces, two 12" pieces
2 | Aluminum four arm knob with 1/4"-20 Thread, 3" Long Stud, 1-1/2" Wide Head | $10.80 | $21.60 | 6085K12 | https://www.mcmaster.com/catalog/6085K12
2 | 18-8 Stainless Steel Flanged Knurled-Head Thumb Nut 1/4"-20 Thread Size, 3/8" High | $4.57 | $9.14 | 95150A170 | https://www.mcmaster.com/catalog/95150A170
1 | Self-Retaining Washers 1/4" and M6 Screw, 0.375" ID, 0.052"-0.072" Thick, Black | $8.89 | $8.89 | 91755A157 | https://www.mcmaster.com/catalog/91755A157 | Retains knob bolt and fills gap between case lip and padlock hole
 |  |  | $151.08

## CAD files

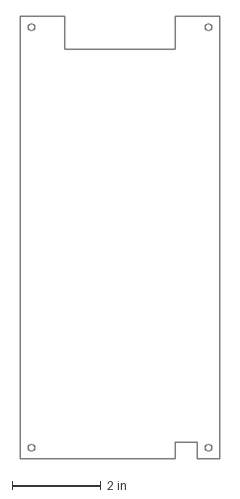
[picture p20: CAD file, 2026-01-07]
dxf/Power.dxf
4.50 x 10.0 in

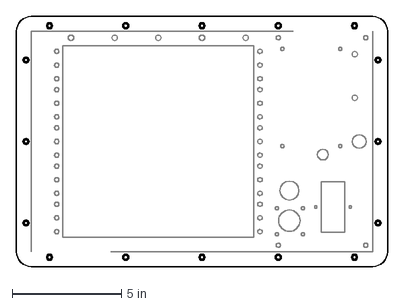
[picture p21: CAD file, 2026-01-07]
dxf/Panel.dxf
17.0 x 11.5 in

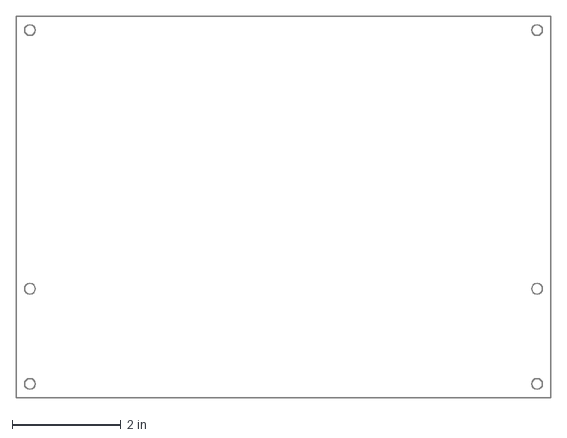
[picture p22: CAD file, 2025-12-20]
dxf/USB.dxf
9.81 x 7.00 in

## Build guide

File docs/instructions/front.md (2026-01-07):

# Front Plate

1. Prep the front panel. We had to add some holes post manufacturing, due to design changes, but if you follow the included [drawings](https://github.com/jagould2012/cyberdeck/blob/main/dxf/Panel.dxf) and drill [positions](https://github.com/jagould2012/cyberdeck/blob/main/plate_drill.csv), your plate will arrive from DataPro compeletely ready.

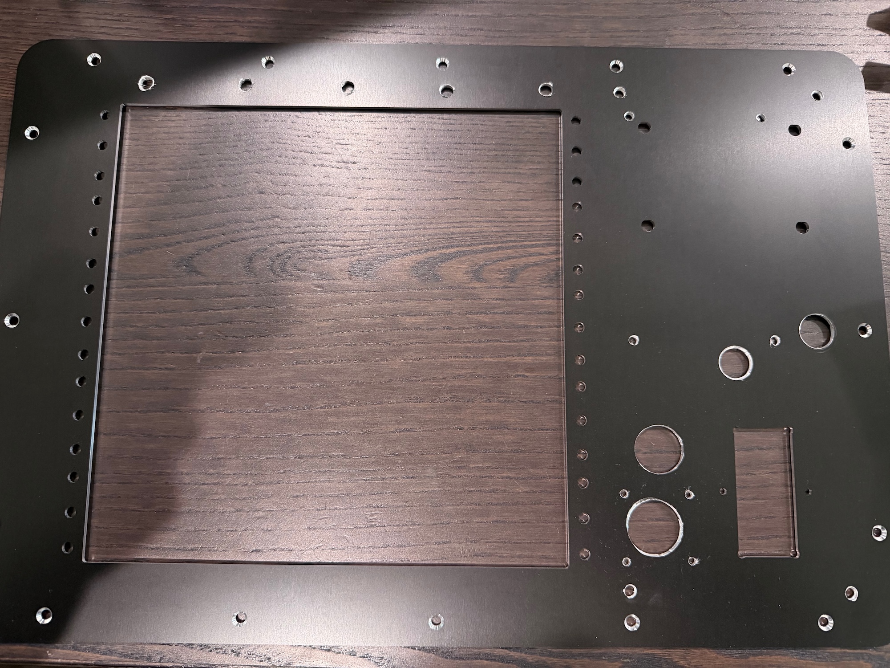
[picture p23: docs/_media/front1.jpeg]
holes


2. Begin to populate the panel - add standoffs, install power switch and inlets, and add RF cables.

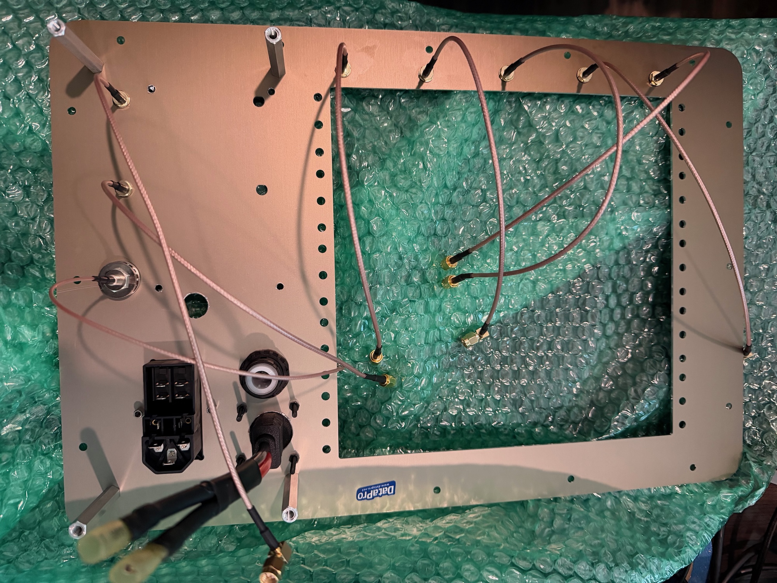
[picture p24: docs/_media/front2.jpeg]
standoffs


3. Install the screens and Raspberry Pi shelf using either standoffs where specified, or lock nuts.

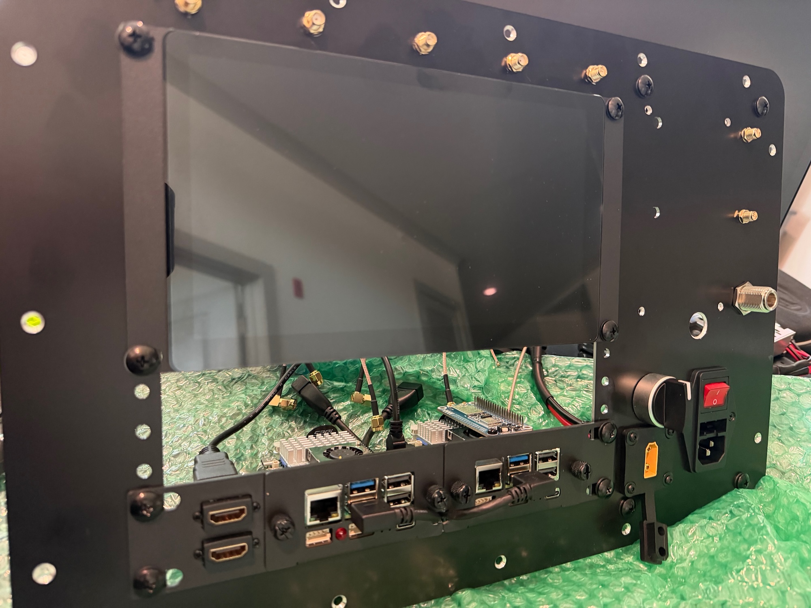
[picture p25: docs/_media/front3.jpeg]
screen


4. Prepare all the cables for the installation of the sub-assemblies.

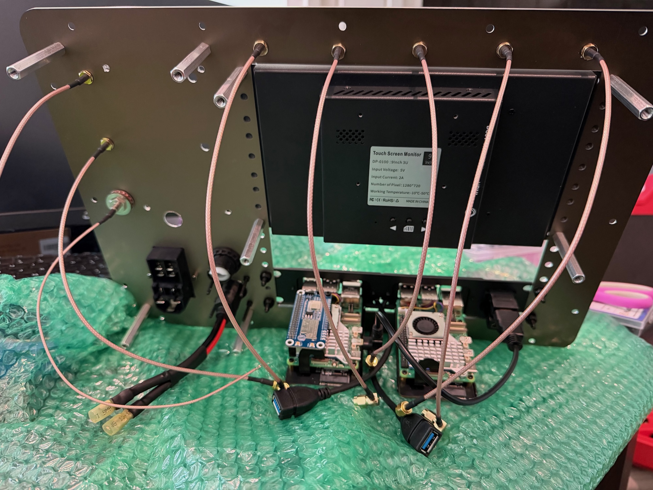
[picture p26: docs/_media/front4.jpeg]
rf

<div class="caption">Note: N-connector shown in this picture was later replaced with right angle connector due to clearance issues. See bill of materials.</div>

5. Wire the HDMI cables up to the Raspberry Pi and secure them with small cable ties. HDMI 0 goes to the LCD touchscreens and HDMI 1 goes to the plate mounted HDMI pass through.

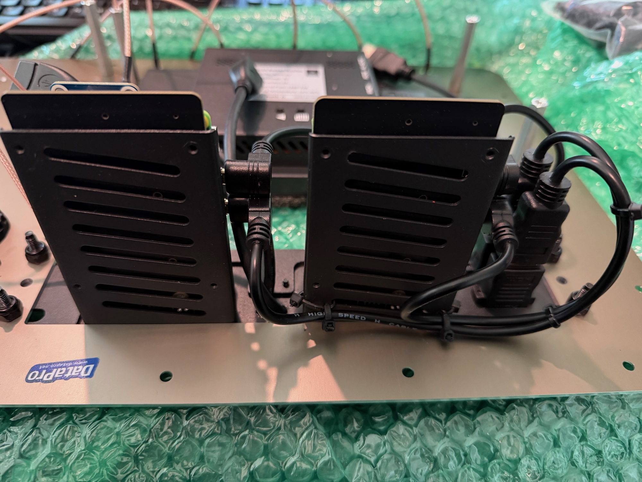
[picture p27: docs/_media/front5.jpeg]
pi


6. Plug in HDMI and USB cables to the touchscreens before installing other panels.

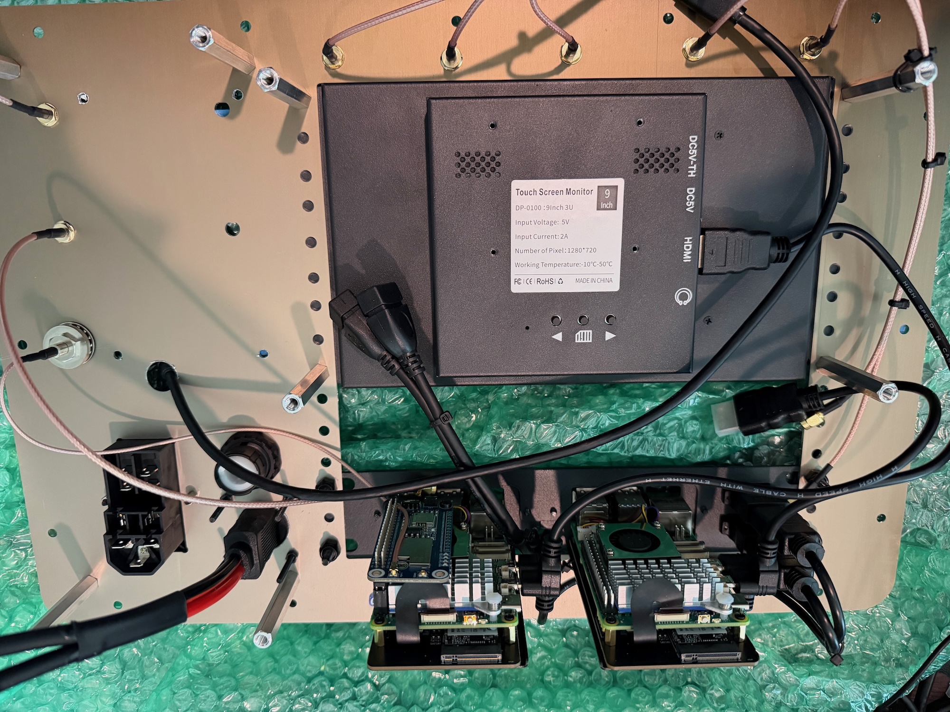
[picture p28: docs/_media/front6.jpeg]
hdmi

<div class="caption">Note: N-connector shown in this picture was later replaced with right angle connector due to clearance issues. See bill of materials.</div>

7. While working on the panel, we recommend installing a piece of foam over touchscreens to prevent them from being scratched.

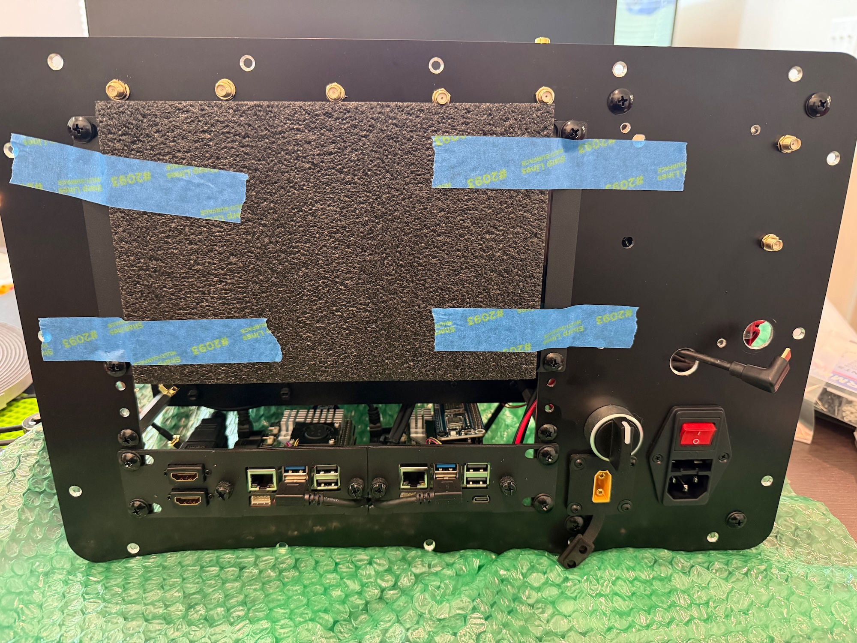
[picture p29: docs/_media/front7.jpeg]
foam

<div class="caption">Note: Right angle USB connector shown in this picture was later upgraded to more compact flex cable, shown in picture below. See bill of materials.</div>

8. Install the Mayham Portapak, right angle slim USB cable, and GPS antenna. Color ring stickers were cut on a vinyl cutter to color code the antenna connectors and a corresponding color strip was wrapped around the antenna.

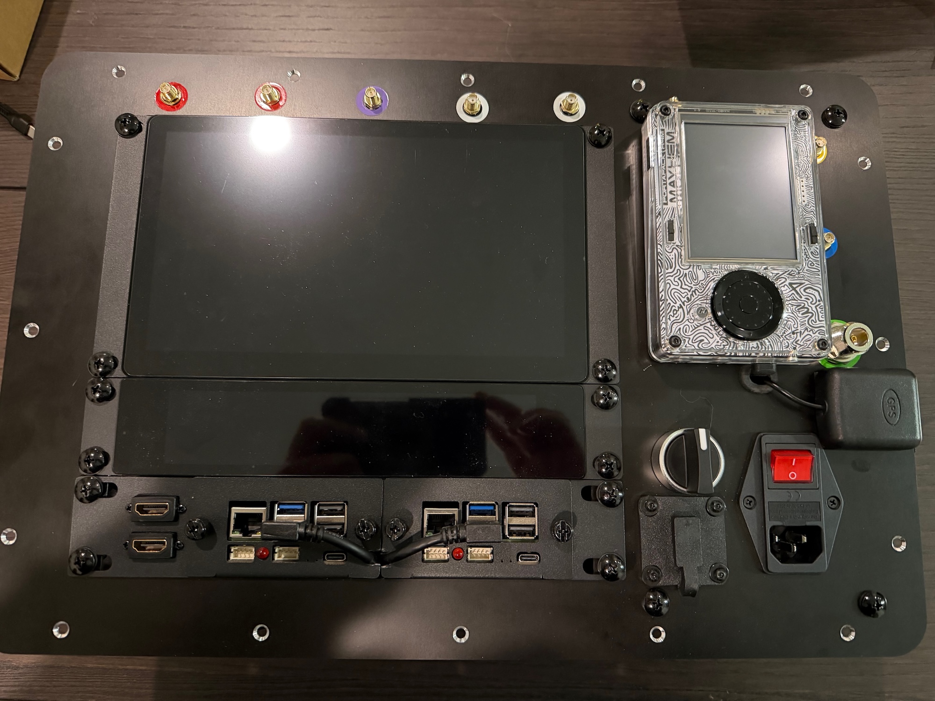
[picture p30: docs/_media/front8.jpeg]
mayhem


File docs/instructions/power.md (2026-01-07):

# Power Board

1. Print out the CAD drawings of the panel from the repo. Use them as a template to cut the ABS sheets to size.

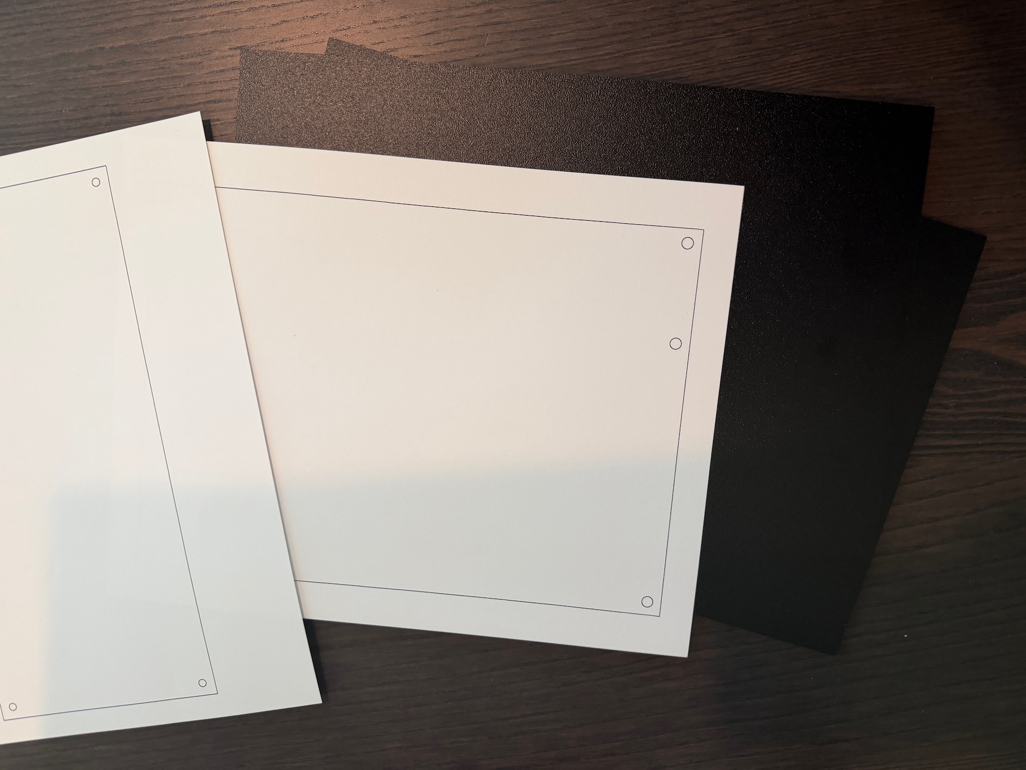
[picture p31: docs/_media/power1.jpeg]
cad


2. If you don't have an apropriate power saw like a band saw, a speciality PVC saw can purchased on Amazon.

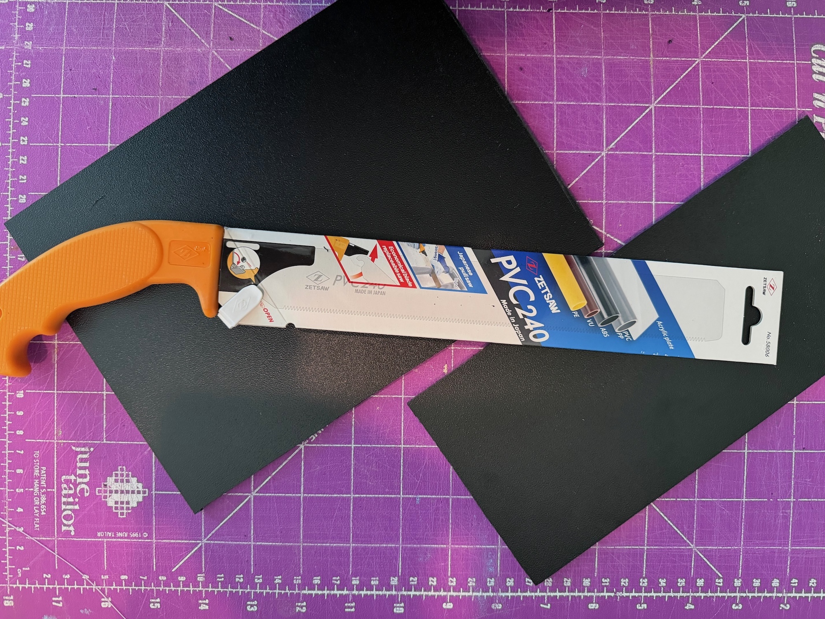
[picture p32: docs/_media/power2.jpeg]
saw


3. Use masking tape to layout the holes for the power supplies. 

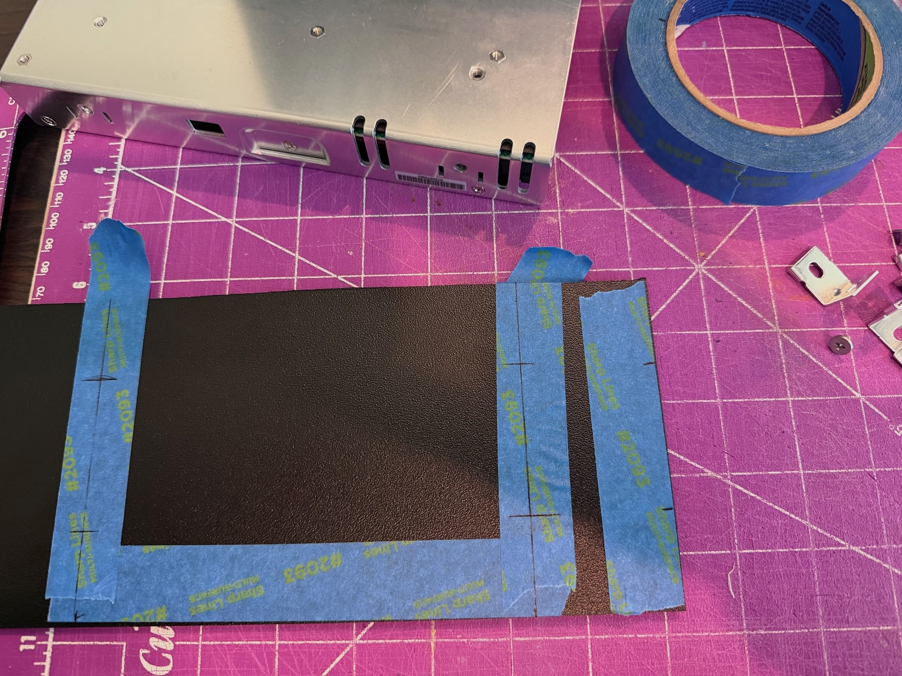
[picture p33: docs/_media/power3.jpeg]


4. We found it helpful to draw the components that mount on the main aluminum faceplate on the masking tape so you know what space they will occupy.

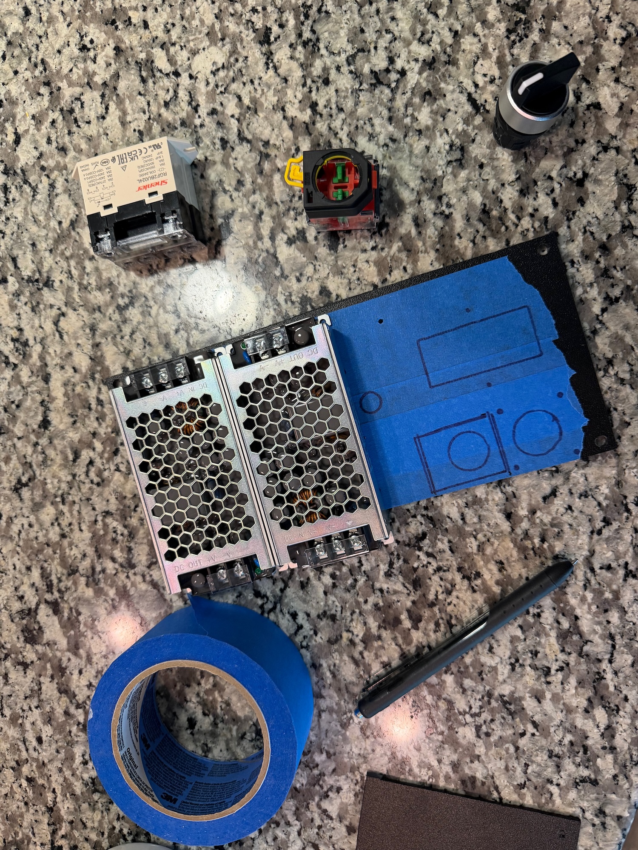
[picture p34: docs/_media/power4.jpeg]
layout


5. Mount the supplies using double sided tape, short standoffs, and M3 bolts and nuts. The 5v supplies will hang off the panel about 1", and will extend under the USB panel. This is by design. Orient the output side of the supply towards the USB panel, and the input side towards the case.

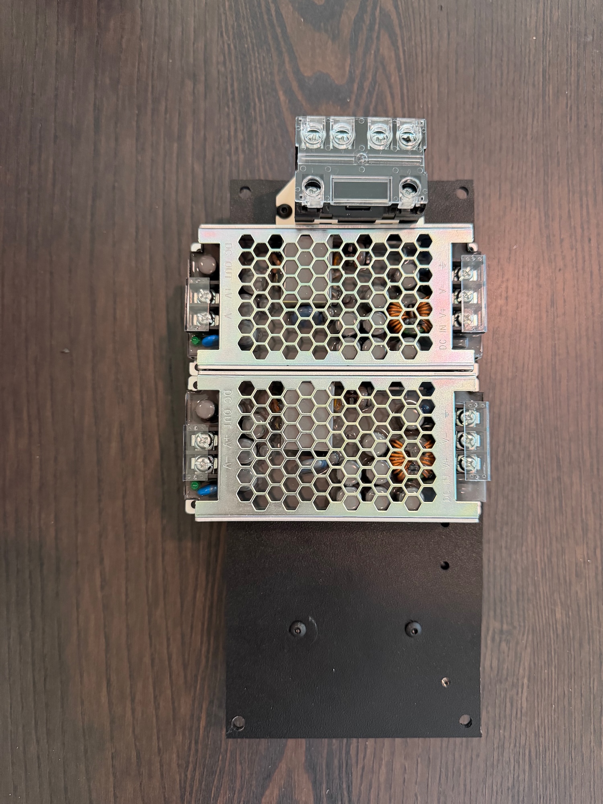
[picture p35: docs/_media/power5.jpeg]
supplies

<div class="caption">Note: relay in photo is not inverted. Photo was taken before modification added in step 13</div>

6. The double sided foam tape and standoffs will allow room for the screws that mount the 24vdc supply, which go into the threaded inserts on the bottom of the supply.

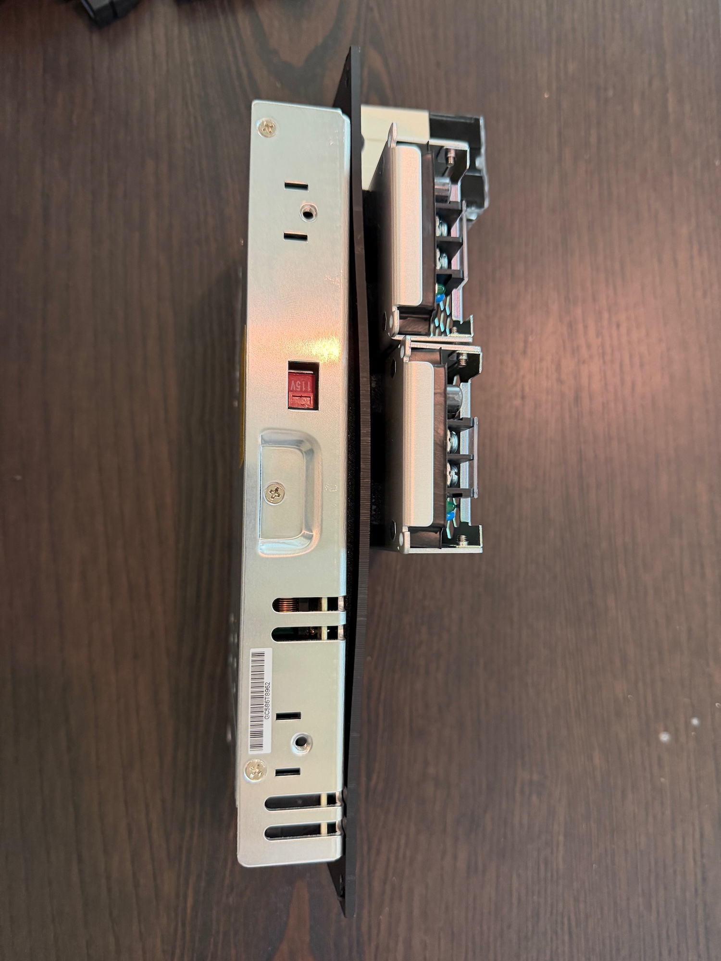
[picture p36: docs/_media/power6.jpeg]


7. The 24vdc supply mounts on the backside of the panel, with the terminals towards the bottom (closest to the AC input and switches).

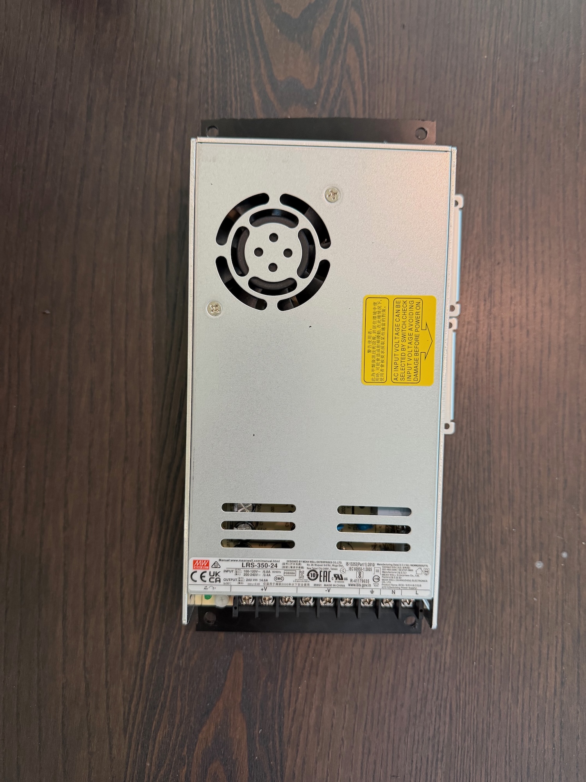
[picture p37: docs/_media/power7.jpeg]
large


8. Wire two positive and two negative wires to the output of the 24vdc supply. One set of wires go to the NO contacts of the relay (terminal 2 red, terminal 6 black). The second positive goes to input one of the switch (terminal 13), and output one of the switch (terminal 14) goes to the coil of the relay (terminal 0). The second negative goes to the relay coil (terminal 1).

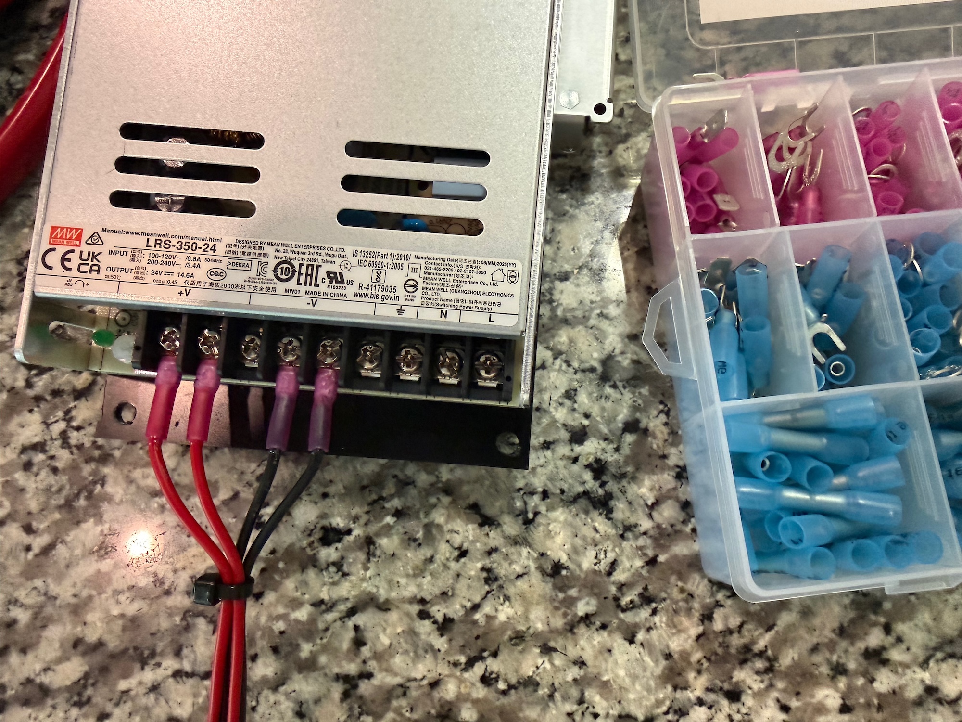
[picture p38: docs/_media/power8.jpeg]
wiring


9. Heatshrink crimp forks are recommended for larger guage wire and large screw terminals.

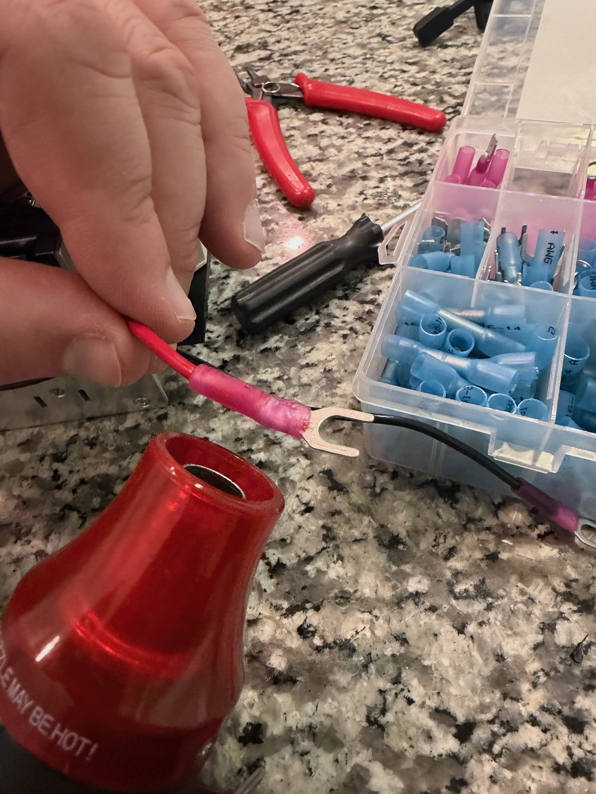
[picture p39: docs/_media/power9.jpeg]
forks


10. Crimp ferules work great for smaller gauge wires connecting to smaller screw terminals.

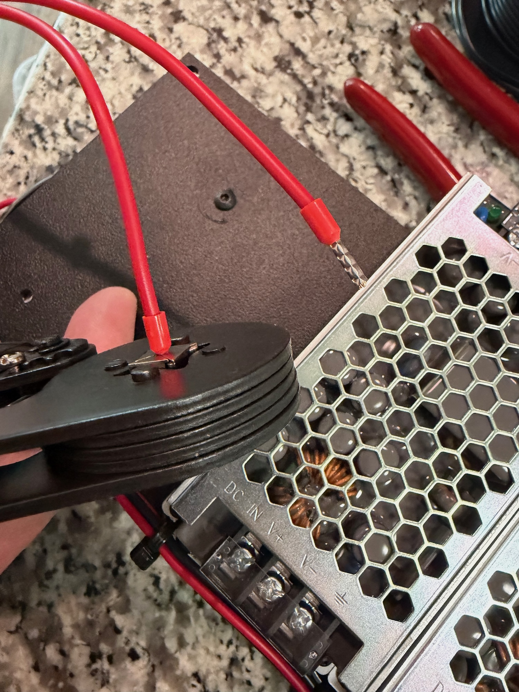
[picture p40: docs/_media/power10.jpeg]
ferule


11. Cut the majority of the wire from the XT90 input plug, leaving about 4 - 5 inches. Crimp spade terminals on and use heatshrink to reinforce the connection.

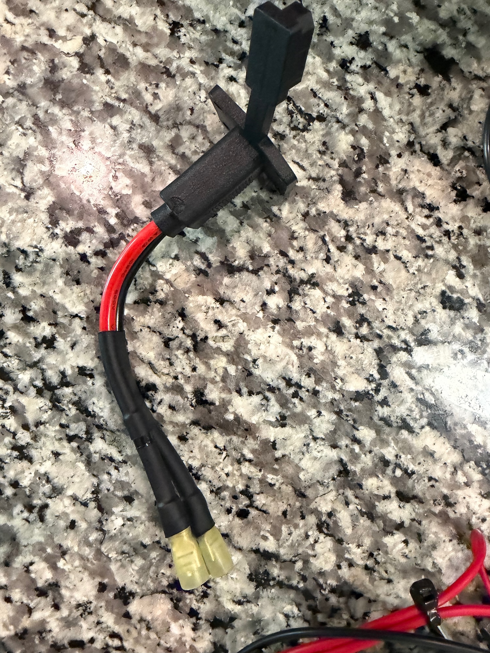
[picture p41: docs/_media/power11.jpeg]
dc


12. Daisy chain the power input from the relay through the 5vdc power supplies and to the DC input via the switch. The DC input feeds from one end of the circuit, and the 24vdc power supply from the other, however they cannot be live at the same time due to the switch and relay. See schematic below.

* Run a pair of wires from the output of the relay NO contacts (terminals 4 red, terminal 8 black) to the input of the first 5v supply. 

* Continue wiring around the outside of the panel connecting a small set of jumpers from the input of the first 5vdc supply, to the input of the second 5vdc supply. 

* Connect the positive (red) of the second 5vdc supply input to a 3 way connection - one feeding a set of jumpers over to the 12vdc supply on the USB panel, and the other to the second output on the switch (terminal 24). We recommend using a spade terminal for the USB panel feed side of the connection so the boards can be disconnected if necessary.

* Connect the negative (black) of the second 5vdc supply input to a 3 way connection - one feeding a set the jumpers over to the 12vdc supply on the USB panel, and the other to black of the XT90 input. 

* Finally, connect a wire from the positive of the XT90 connector to the second input of the switch (terminal 23).

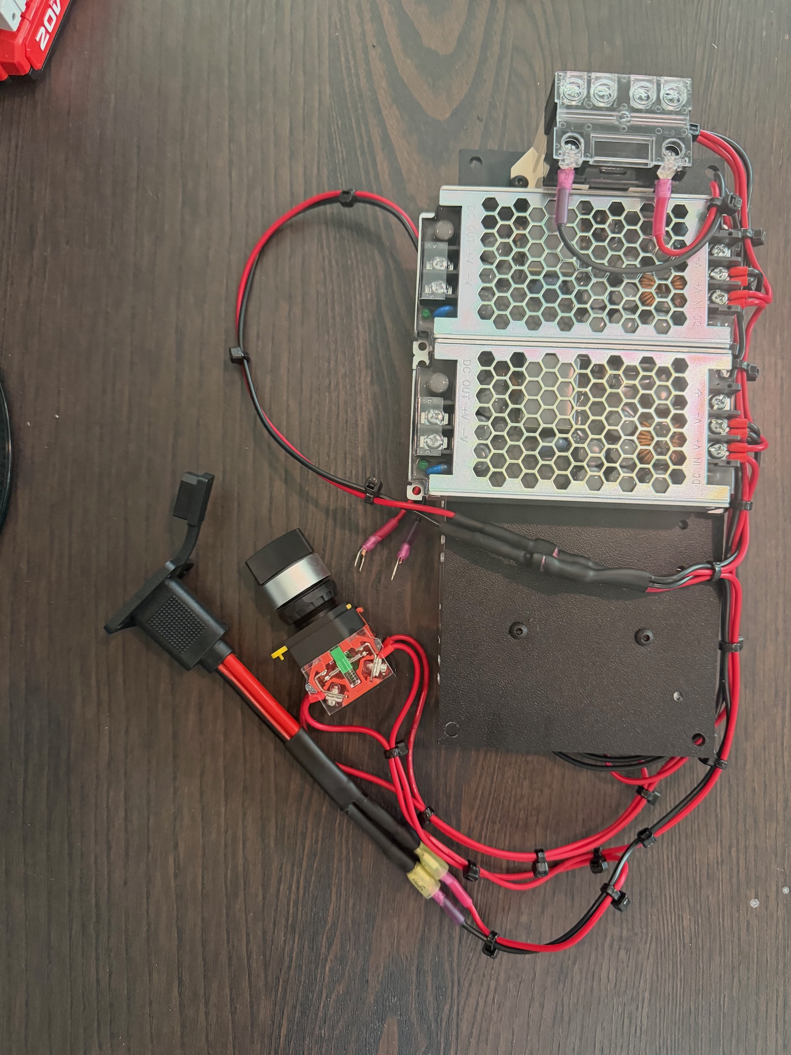
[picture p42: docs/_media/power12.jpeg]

<div class="caption">Note: relay in photo is not inverted. Photo was taken before modification added in step 13</div>

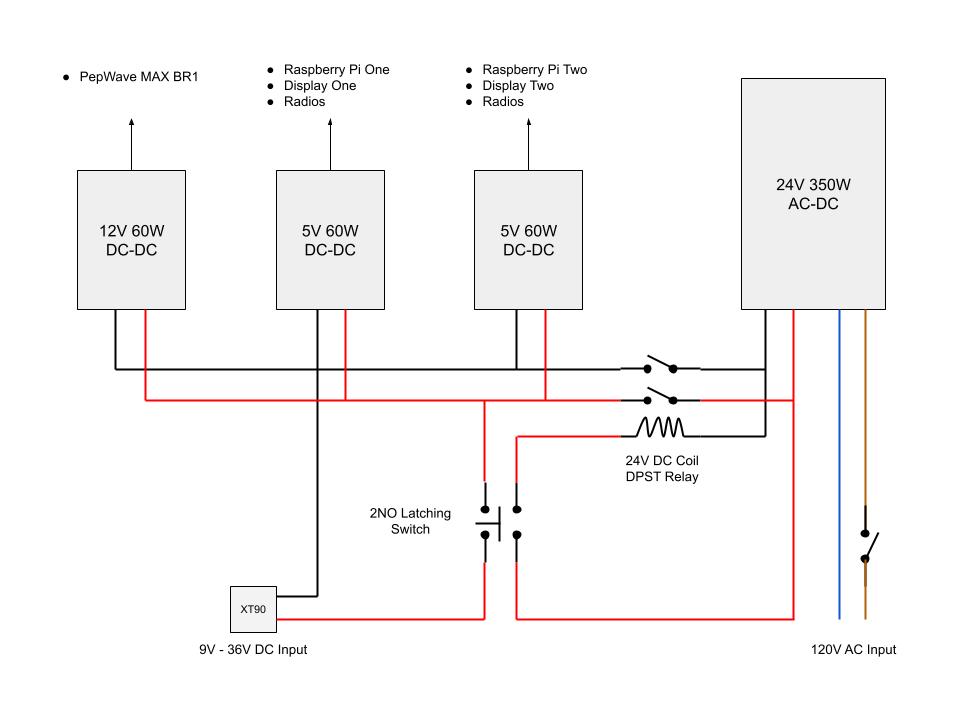
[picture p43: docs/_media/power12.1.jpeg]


13. To make it easer to slide the assembly in and out of the case, invert the relay and notch the panel to allow the screw terminals to recess through the board. The terminals can now be connected from the inside of the panel facing out, so they don't catch on the case frame.

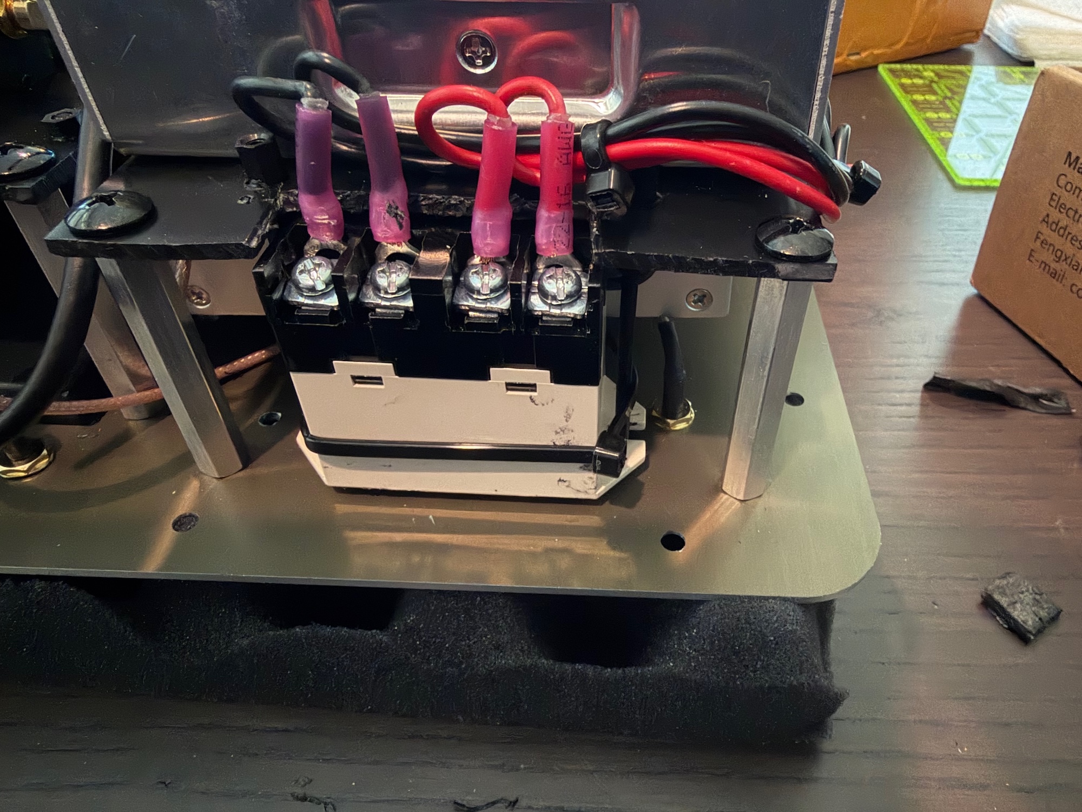
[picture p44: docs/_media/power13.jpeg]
relay


14. Cut a similar notch on the other end of the panel to allow the 120vac input wires to lay inside the permiter of the panel.

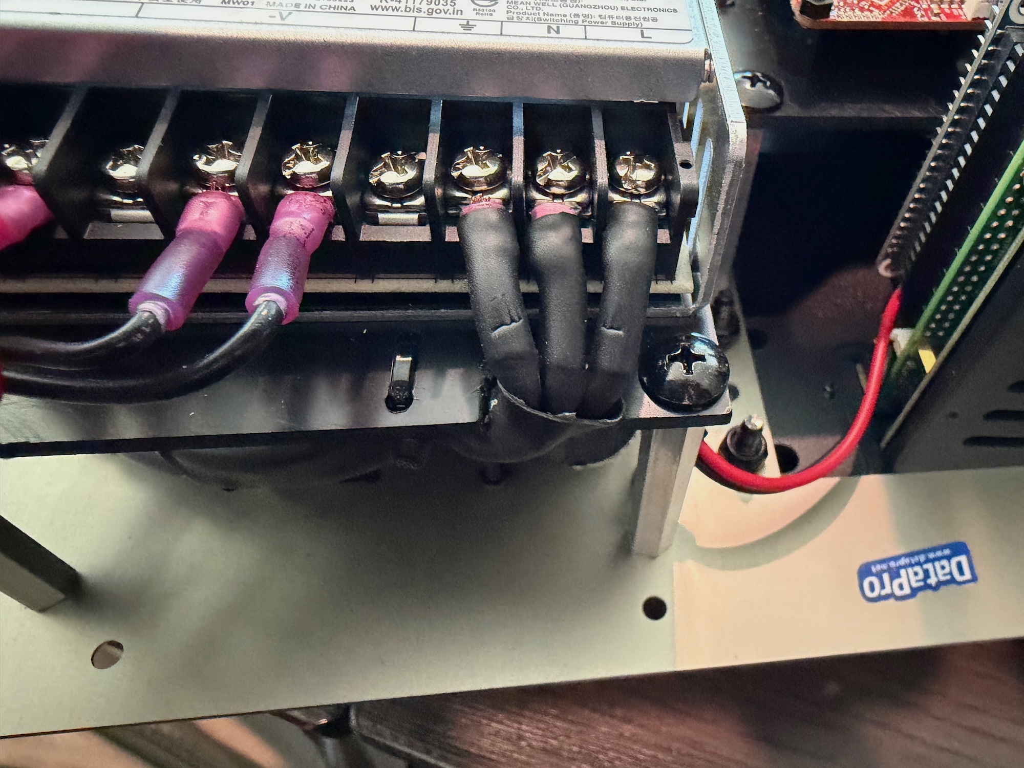
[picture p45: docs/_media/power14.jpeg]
notch


15. Heatshrink the 120vac wires and secure them to the panel with a small cable tie to pull them underneath. Add spade connectors and connect to the fused power switch.

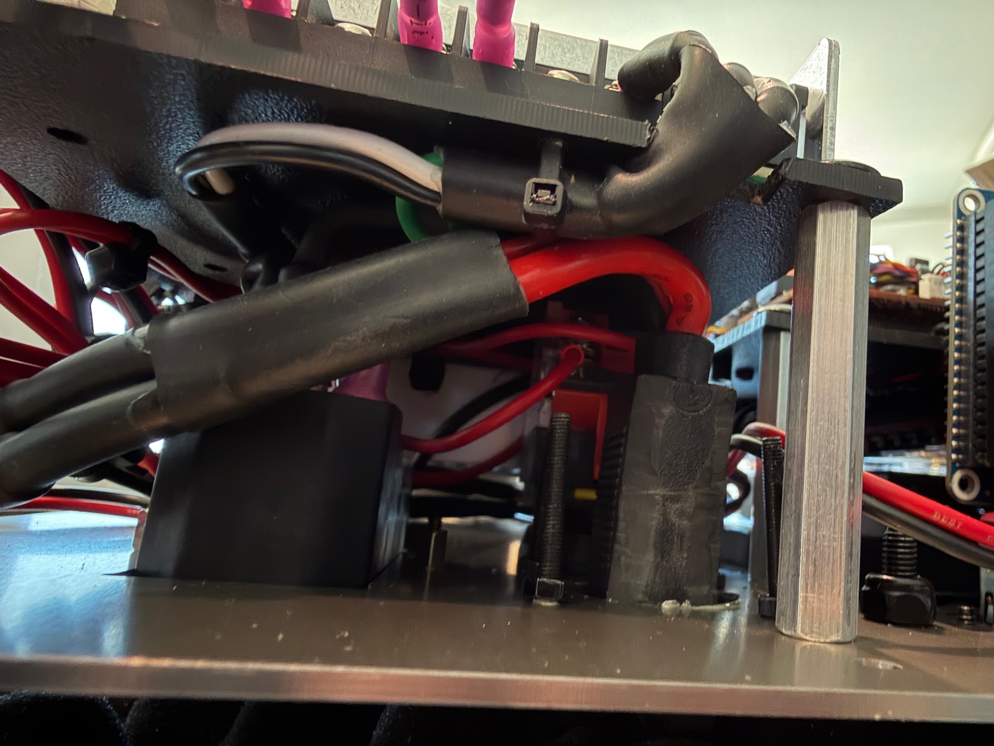
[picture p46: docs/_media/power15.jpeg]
line


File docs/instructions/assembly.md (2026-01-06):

# Assembly and Power Up

<div class="todo">
	<div class="title">Under Construction - Check back soon</div>
	TODO - add sub-system assembly photos
</div>

5. Before powering up, check all power circuits for shorts. A USB power meter is recommended for checking all the 5vdc USB plugs for constant and stable power before plugging them into sensitive equipment.

power

6. Before installing all 16 bezel screws, we recommend a full system test. Connect your antennas and verify signal to each radio, plug in USB keyboard and external monitor, check both power sources, and verify the Ethernet and WiFi is working.

power

7. Two sheets of neoprene foam are placed below the keyboard to protect the screens in transit. Antennas are stored in small neoprene pouches and cables secured with velcro strips.

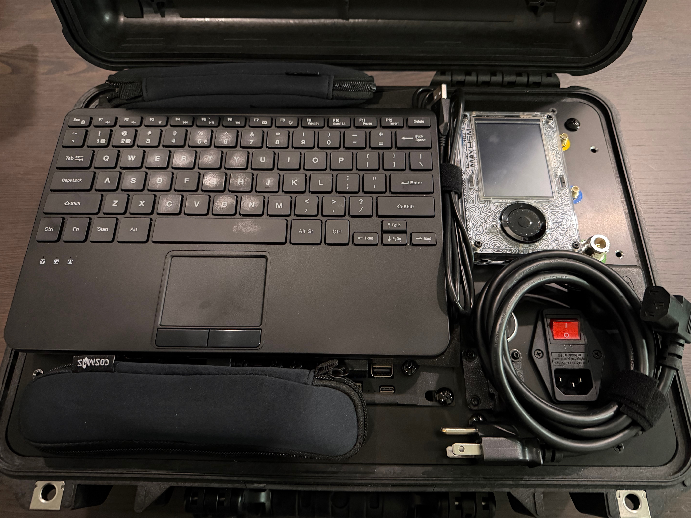
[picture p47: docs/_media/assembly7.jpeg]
power


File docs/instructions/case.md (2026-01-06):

# Pelican Case

1. Drive the threaded inserts into the frame. While the Pelican instructions say to use the tip of a screwdriver, we found a brass drift is a much better tool.

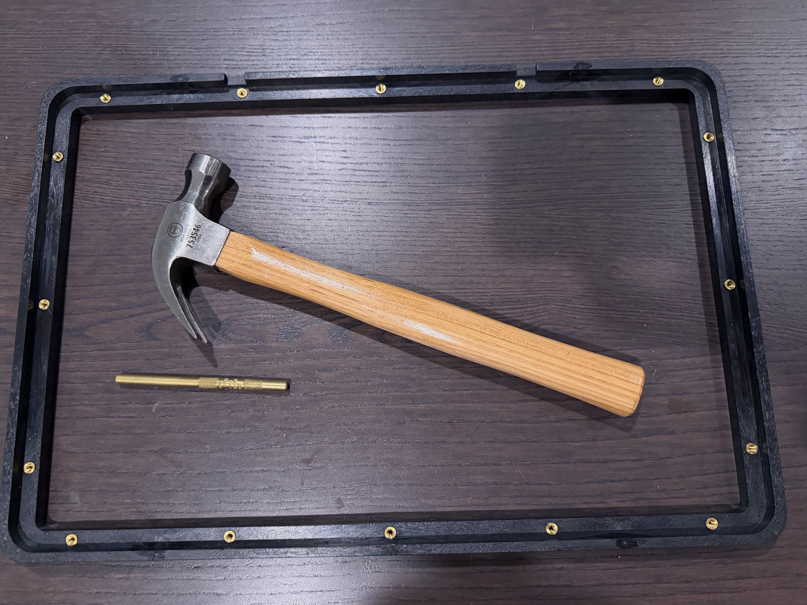
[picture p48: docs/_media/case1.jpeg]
frame


2. Using a cordless drill, drive the four supplied screws into the case. You will notice that the pre-drilled holes in the frame align with the thick ribs of the case, where the screws will not penetrate the outside of the case.

3. Insert the gasket into the frame. There is plenty of gasket, so don't stretch it as you work around the frame.

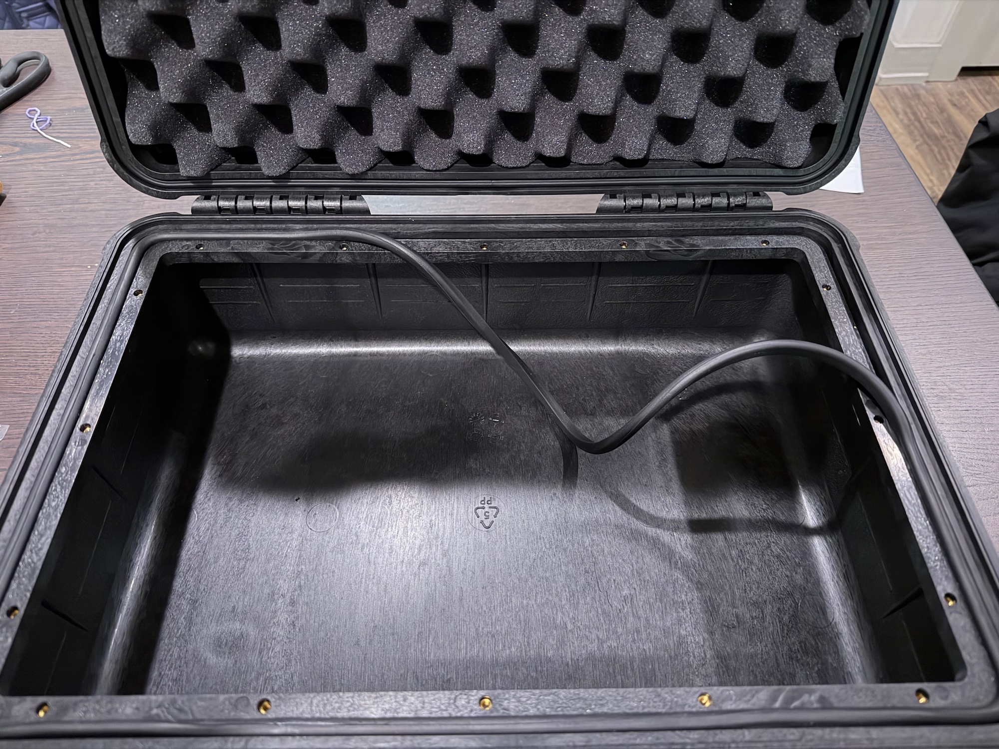
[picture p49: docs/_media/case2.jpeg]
gasket


4. Remove the foam from the lid and line it with two adhesive neoprene sheets. You will need to cut around the screw mounts in the lid. We found it easiest to measure cuts on one sheet, then lay the second piece face to face with the first, mirroring the cuts.

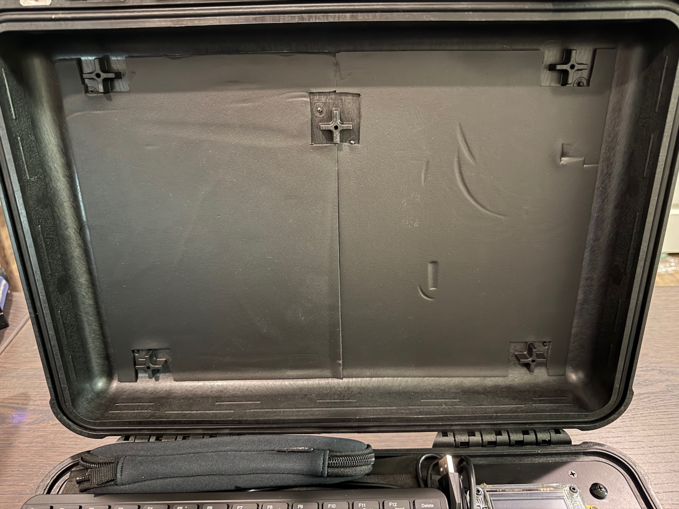
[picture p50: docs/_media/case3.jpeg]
lining


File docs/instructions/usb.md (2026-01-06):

# USB Panel

1. Terminal strips are attached to the back of the USB panel to distribute 5vdc power from the two power supplies. Each strip powers a Raspberry Pi, an LCD touchscreen, and one USB hub.

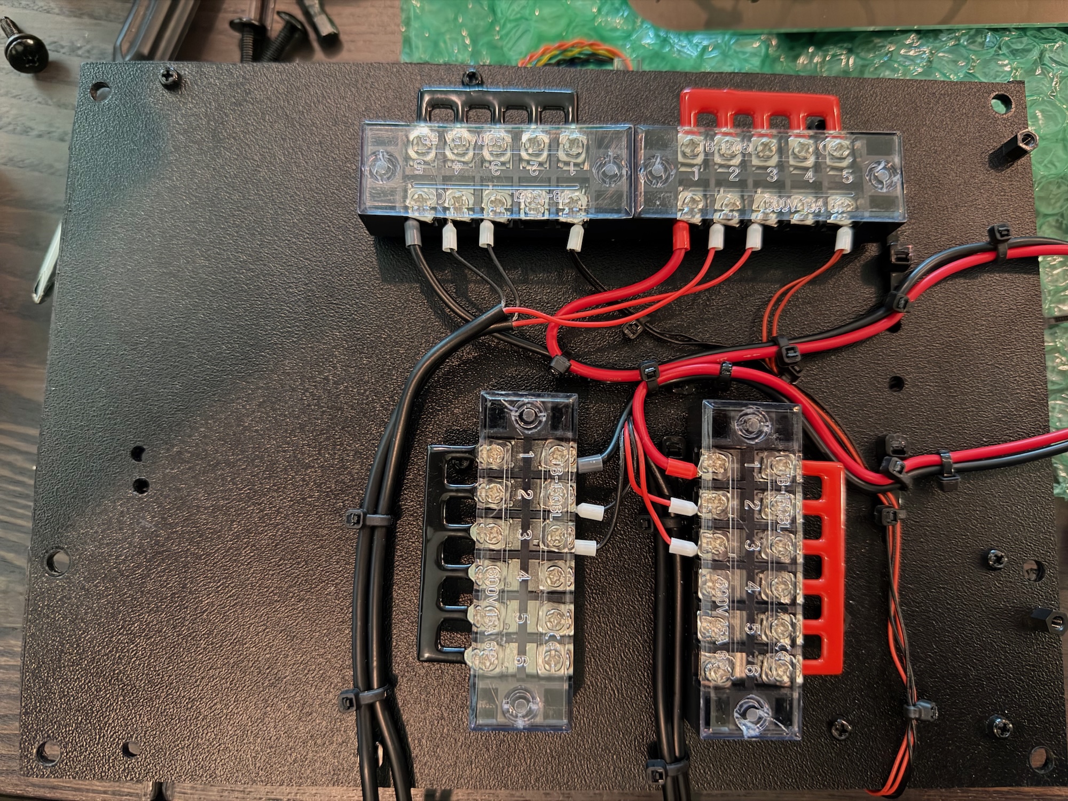
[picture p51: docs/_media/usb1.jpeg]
power


2. We used a vinyl cutter to cut letters A and B to designate the two redundant halfs of the compute section. Vinyl strips 1/4" x 1.5" where cut to mark each end of all USB, HDMI, and power cables. This assists in debugging as you dont have to trace wires back to the Pi boards to know which section it belongs to.

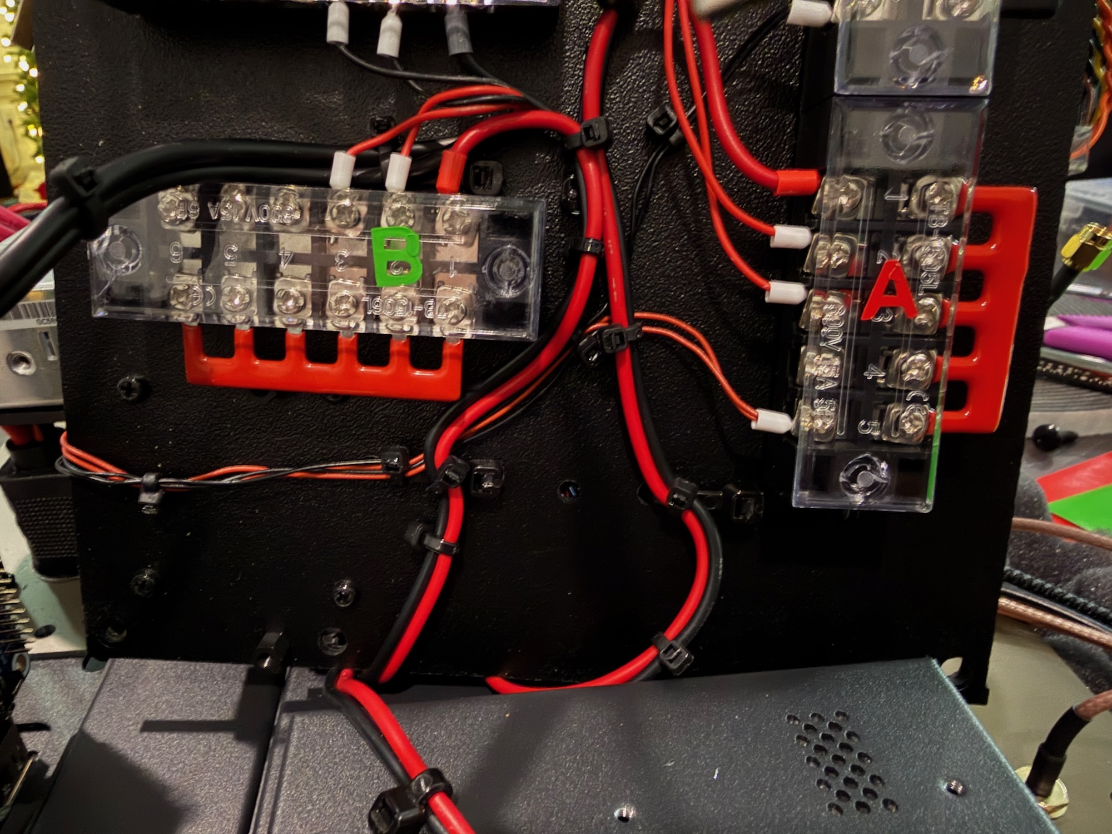
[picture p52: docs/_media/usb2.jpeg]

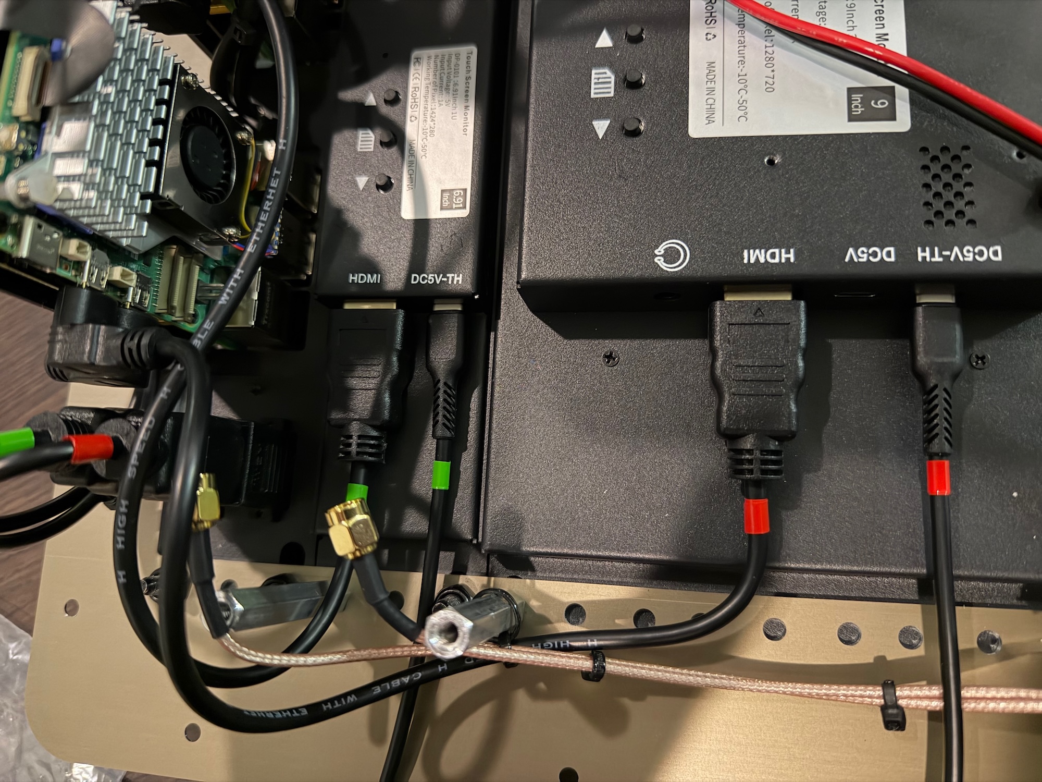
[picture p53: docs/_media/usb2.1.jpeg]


<div class="todo">
	<div class="title">Under Construction - Check back soon</div>
	TODO - add new USB hub photos
</div>

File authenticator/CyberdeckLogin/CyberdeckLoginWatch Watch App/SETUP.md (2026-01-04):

# Apple Watch Support Setup

## Adding Watch Target to Xcode Project

### 1. Create Watch Target

1. Open `CyberdeckLogin.xcodeproj` in Xcode
2. File → New → Target
3. Select **watchOS** → **App**
4. Configure:
   - Product Name: `CyberdeckLogin Watch App`
   - Bundle Identifier: `com.yourcompany.CyberdeckLogin.watchkitapp`
   - Language: Swift
   - User Interface: SwiftUI
   - Watch App Type: **Watch App** (not Watch App for iOS App)
   - Include Notification Scene: No (optional)
5. Click **Finish**

### 2. Add Watch Files

Copy the Watch files to the Watch target:

```
app/Watch/
├── CyberdeckLoginWatchApp.swift   (replace generated App file)
├── PhoneConnectivityService.swift
├── WatchDevice.swift
├── WatchContentView.swift
└── WatchDeviceDetailView.swift
```

Add each file to the Watch target (select the Watch target in File Inspector).

### 3. Add WatchConnectivity to iPhone App

1. Add `WatchConnectivityService.swift` to the **iPhone target**
2. Initialize it in `CyberdeckLoginApp.swift`:

```swift
import SwiftUI

@main
struct CyberdeckLoginApp: App {
    @StateObject private var bleManager = BLEManager()
    
    init() {
        // Configure Watch connectivity
        WatchConnectivityService.shared.configure(bleManager: BLEManager())
    }
    
    var body: some Scene {
        WindowGroup {
            ContentView()
                .environmentObject(bleManager)
        }
    }
}
```

### 4. Configure Capabilities

#### iPhone Target:
1. Select iPhone target → Signing & Capabilities
2. Add **Background Modes**:
   - Uses Bluetooth LE accessories
   - Background fetch (optional)

#### Watch Target:
1. Select Watch target → Signing & Capabilities
2. No special capabilities needed (WatchConnectivity is automatic)

### 5. Update Info.plist (if needed)

The Watch app doesn't need Bluetooth permissions since it communicates through the iPhone.

### 6. App Groups (Optional - for shared data)

If you want to share data between iPhone and Watch via UserDefaults:

1. Add **App Groups** capability to both targets
2. Use the same group identifier: `group.com.yourcompany.CyberdeckLogin`

## Architecture

```
┌─────────────────┐         ┌─────────────────┐
│   Apple Watch   │         │     iPhone      │
├─────────────────┤         ├─────────────────┤
│                 │         │                 │
│  WatchContent   │◄──WC───►│   BLEManager    │
│      View       │         │                 │
│        │        │         │        │        │
│        ▼        │         │        ▼        │
│  PhoneConnect   │         │  WatchConnect   │
│    Service      │         │    Service      │
│                 │         │        │        │
└─────────────────┘         │        ▼        │
                            │   Cyberdeck     │
                            │   (via BLE)     │
                            └─────────────────┘

WC = WatchConnectivity Framework
```

## Communication Flow

### Getting Devices
1. Watch sends `getDevices` message
2. iPhone replies with array of discovered devices
3. Watch displays device list

### Authentication
1. User taps "Unlock" on Watch
2. Watch sends `authenticate` message with deviceId
3. iPhone:
   - Connects to device (if needed)
   - Performs BLE authentication
   - Signs challenge with private key
4. iPhone sends result back to Watch
5. Watch shows success/failure with haptic feedback

## Testing

1. Run iPhone app on device
2. Run Watch app on paired Apple Watch or simulator
3. iPhone must be running for Watch to work
4. Test with Watch simulator: iPhone Simulator can pair with Watch Simulator

## Notes

- Watch cannot do BLE directly for this use case (needs iPhone)
- Authentication requires iPhone to be reachable
- Watch app shows cached device list when iPhone is briefly unreachable
- Haptic feedback confirms authentication result

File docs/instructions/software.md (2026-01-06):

# Software

<div class="todo">
	<div class="title">Under Construction - Check back soon</div>
	TODO - Ansible playbook instructions
</div>

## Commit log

2025-12-18 Bill of materials, plate drill coordinates, and README update.
    [bom.csv, plate_drill.csv]
2025-12-18 Power diagram.
2025-12-20 Added 12V power supply, PepWave radio, dxf files.
    [Panel.dxf, Power.dxf, USB.dxf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]
2025-12-20 Update panel, add PepWave license to BOM
    [bom.csv]
2025-12-20 Update bom
    [bom.csv]
2025-12-20 Update power schematic
2025-12-20 Added BotBlox
    [bom.csv]
2025-12-20 Update power mounting
    [Panel.dxf, plate_drill.csv]
2025-12-27 Power setting due to Raspberry PI limiting to 600ma when not connected to USB-PD negotiating power supply.
2025-12-27 Updated BOM
    [bom.csv]
2026-01-01 Stand sketchup, bom, and images
    [stand.bom.csv]
2026-01-02 Arm now working
2026-01-05 Update sketchup and bom
    [bom.csv]
2026-01-07 Clarify power wiring
